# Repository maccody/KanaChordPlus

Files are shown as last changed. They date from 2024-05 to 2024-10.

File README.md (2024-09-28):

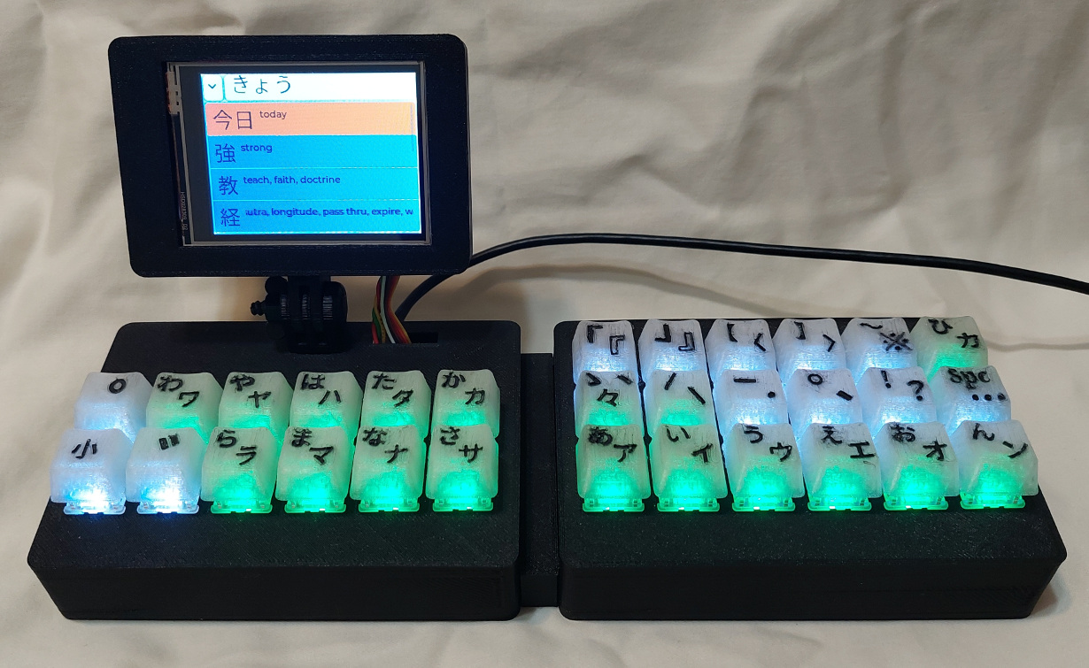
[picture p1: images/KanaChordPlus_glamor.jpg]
KanaChord_glamor

# KanaChord Plus Keyboard 【カナコード・プラス・キーボード】
## Overview 【概要】
KanaChord Plus is an auxiliary keyboard that works in parallel with a standard English keyboard and generates Unicode keyboard macros to render Japanese Kana and Kanji characters.  This allows the user to immediately start typing in Japanese on any supported computer, rather that installing special software and switching language input modes on a single keyboard.  KanaChord Plus can assist the Japanese learner by providing another means to improve their language skills by typing in Japanese, in addition to practicing their reading and speaking skills.  Note that during the composing of this README, KanaChord Plus Keyboard was used to type the Kana and Kanji characters displayed.  KanaChord Plus is a follow-on project of KanaChord Keyboard, which supports typing of just Hiragana and Katakana Unicode characters.

### Writing in Japanese 【日本語で書く】
The Japanese writing system consists of three components: Hiragana, Katakana, and Kanji. Hiragana consists of 48 syllabic characters that are used for some words of Japanese origin and grammatical sentence fragments, e.g., あなた, これ, の (‘you’, ‘this’, possessive particle).  Katakana also consists of 48 syllabic characters that are used for foreign loan words and names, e.g., テーブル, クッキー, マック (‘table’, ‘cookie’, ‘Mac’).  The table below shows the syllabary of Hiragana and Katakana, known collectively as the Kana.
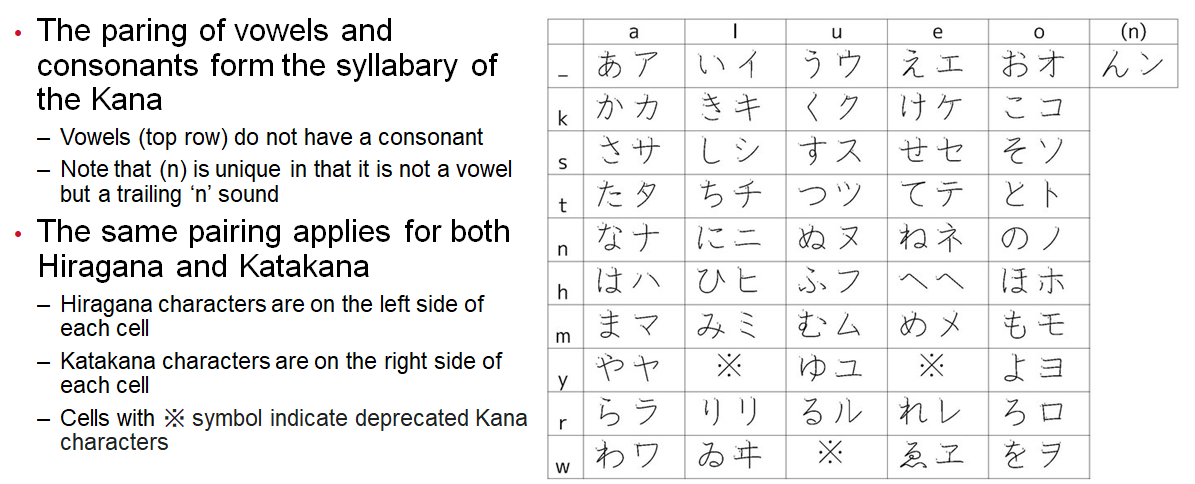
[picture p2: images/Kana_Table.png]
Kana Table


### What about Kanji? 【漢字はどうですか？】
Kanji consists of Chinese logography and conveys main ideas and names in sentences.  A Japanese word containing Kanji can consist one or more Kanji characters, e.g., 私, 東京, 日曜日 (I, Tokyo, Sunday), and Hiragana e.g. 買い物、ご飯、寒い (shopping, meal, cold).  There are currently about fify-thousand Kanji characters and new ones are added on occassion.  In Japan, it is expected that a graduating high-school student, starting from elementary school, learn the Jōyō Kanji【常用漢字】, which contains 2136 Kanji characters that are reqularly used or are found in government documents.  A college graduate, especially with an advanced degree, would be expected to learn a thousand or more additional Kanji usually associated with their major.

### Inspiration for a Keyboard 【キーボードの動機】
Over the last century, there have been a number of mechanical and electro-mechanical keyboards have been developed to type Kana and Kanji characters.  A quick web search for 'japanese keyboard' will provide a number of interesting links to follow.  These keyboards all shared common problems.  They were very expensive and slow at typing compared to contemporary English typewriters.  Only a relatively small subset of Kanji (a few thousand) were suported with these typewriers.

The availability of inexpensive computers in recent decades have obsoleted these typewriters, They have replaced purely hardware solutions with ubiquitious keyboards augmented with software running on the computer.  [There are two methods for typing in Japanese](https://www.coscom.co.jp/learnjapanese801/howjpdo.html).  The first is Romaji Input (ローマ字入力, romaji nyūryoku), which uses combinations of Roman characters to represent Japanese syllables. The second is Kana Input (仮名入力, kana nyūryoku), which uses Japanese Kana characters directly.  The more commonly used method is Romaji Input due to the fewer number of characters on the keyboard to remember.  *Comment: I find it a little sad that a foreign character set has taken precedence over the Japanese native characer set for typing in Japanese!*  Software on the computer implements an Input Method Editor (IME) that takes Romaji Input or Kana Input and predicts one or more Japanese words that may contain Kanji. Junferno's video [The Challenge of Making a Keyboard for Every Language](https://www.youtube.com/watch?v=MBQvN03i4-4) provides a nice overview of the difficulties of creating a keyboard that supports non-English characters and the succession of typewriters by computers with keyboards and IMEs. 

The layout of the Kana table inspires a chording keyboard input method. Chording is where multiple keys are pressed simultaneously on the keyboard to obtain a desired character output.  A [Stenotype](https://en.wikipedia.org/wiki/Stenotype) keyboard is an example of a chording keyboard that is used by court recorders and stenographers.  The illustration below provides further explanation and demonstration of how chording is used on the KanaChordPlus Keyboard.
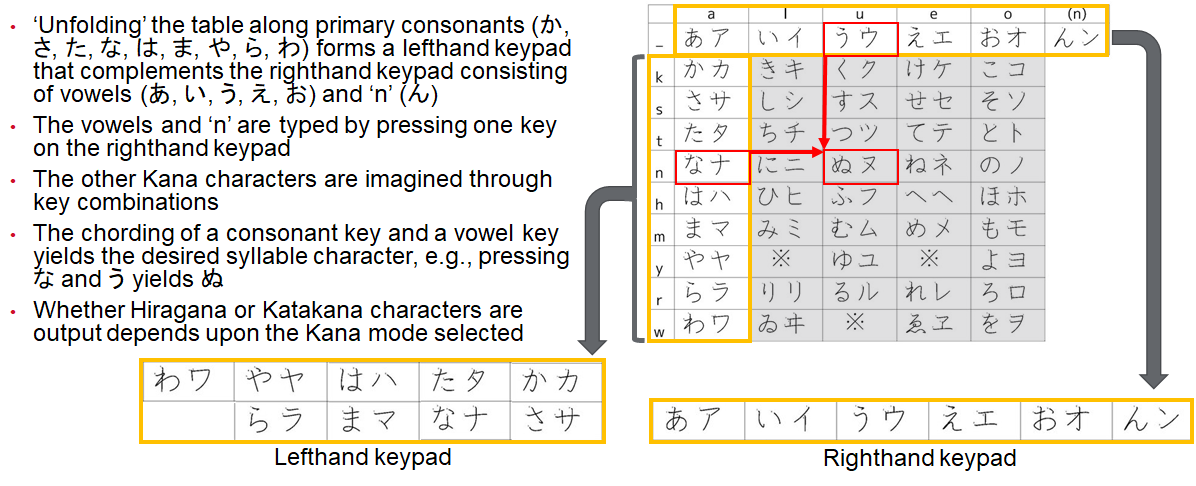
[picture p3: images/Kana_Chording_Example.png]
Kana Chording Example


A chording keyboard concept is sufficient for generating all of the Kana.  It is impractical for Kanji, though, as even a chording keyboard would quickly become impractical when attempting to support more than a few dozen Kanji.  Instead, KanaChord Plus incorporates an 'incremental' IME.  As the Hiragana or Katakana are typed, they are presented on a touch screen along with a list of representative Kanji characters and/or Japanese words containing Kanji.  The list is updated with each new Kana character typed, incrementally.  This is not a word-predictive IME, as the Kanji and Japanese words presented are only those corresponding to the Kana currently typed.  The user can either send the Kana characters typed to the computer or select one of the Kanji characters or Japanese words to replace the Kana characters and send that to the computer instead.

## Features 【特徴】
### Dynamic Key Coloring 【動的なキーの色付け】
KanaChordPlus includes dynamic key coloring that provides indication of character type, Kana mode, and error feedback.  The three Shift keys on the left keypad are normally white:
- Voicing mark, a.k.a. dakuten or ten-ten (ﾞ),
- Plosive mark, a.k.a. handakuten or maru (ﾟ),
- Small characters, a.k.a. chiisai (小), also used to ‘shift’ to alternate punctuation and special characters.

Punctuation keys on the top two rows of the right keypad are also normally white:
- Vertical iteration mark (〳,〴,〵), continuation mark (ー), and separation (・) characters ,
- Sentence pausing (、) and ending characters (。, ! , ?),
- Wide space (labeled **Spc**) and ellipsis (…) characters,
- Commonly-used quotation (「, 」,『, 』), bracket (【, 】,〈, 〉), and special (〜,※) characters.

The Kana and horizontal iteration mark keys (ゝ,ゞ,ヽ,ヾ、々) are green for Hiragana mode or blue for Katakana mode.  The mode is selected by the mode key (ひカ) at upper right-hand corner of the right keypad.
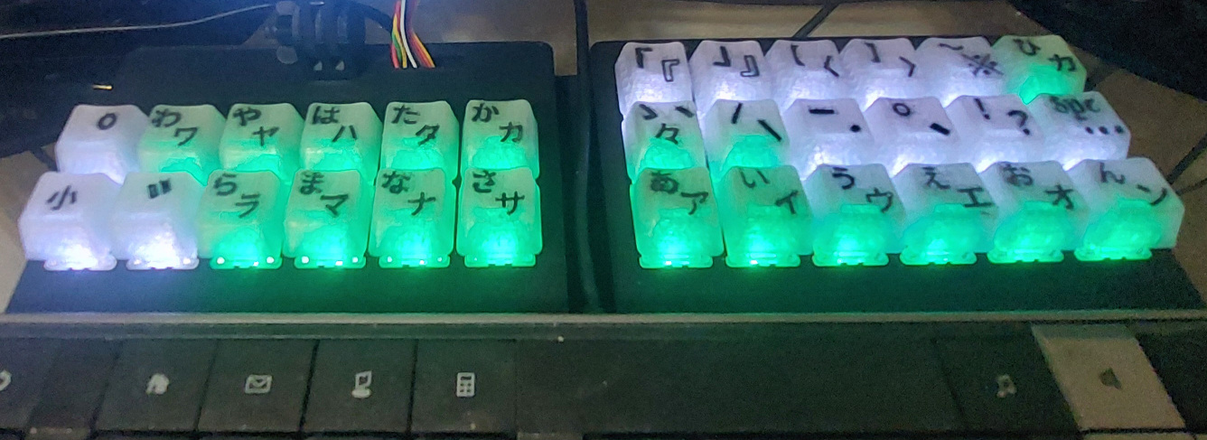
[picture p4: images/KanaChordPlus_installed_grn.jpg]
KanaChordPlus_installed_grn

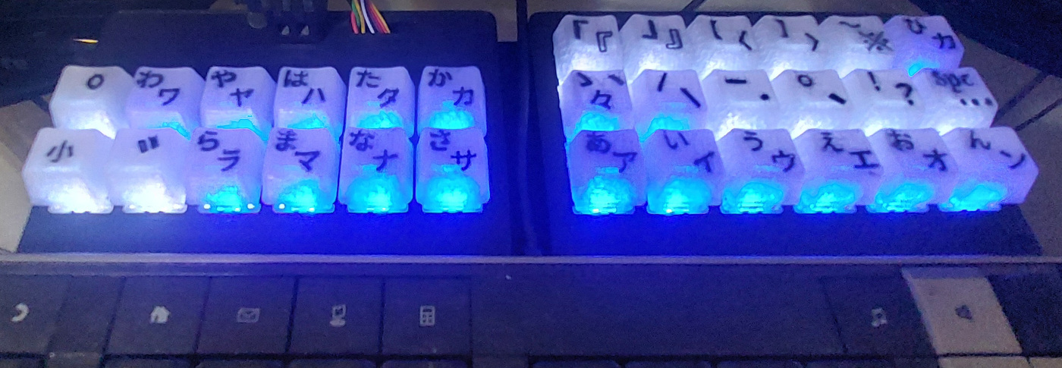
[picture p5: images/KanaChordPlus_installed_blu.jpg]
KanaChordPlus_installed_blu


### Error Feeback 【エラーフィードバック】
Feedback is provided to the user for incorrect key combinations by changing those keys red.  Releasing the keys will cause the keys to revert to their original colors.  Some examples are provded below:

Keyboard error lighting with press of ! and お key combination.
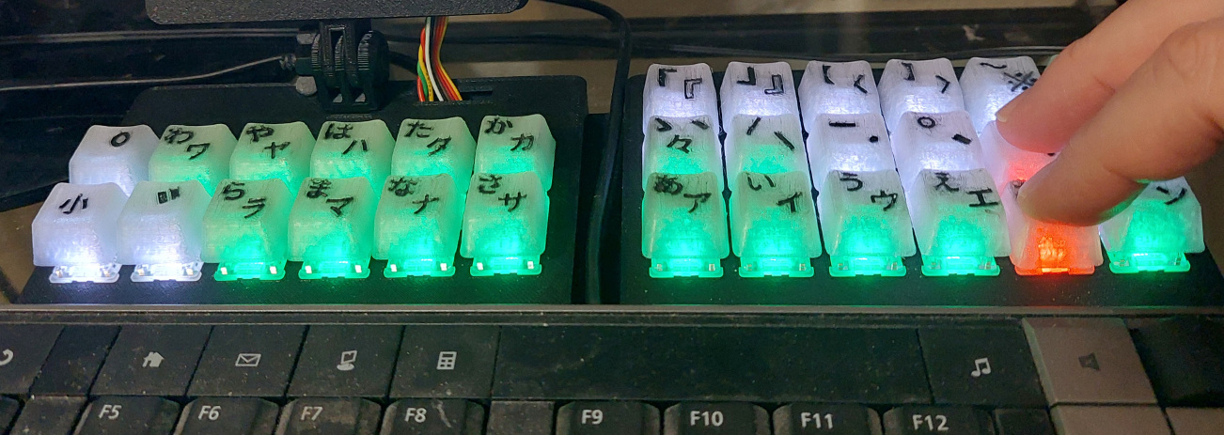
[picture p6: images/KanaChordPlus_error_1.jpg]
KanaChordPlus_error_1


Keyboard error lighting with press of ﾞ, な, and あ key combination.
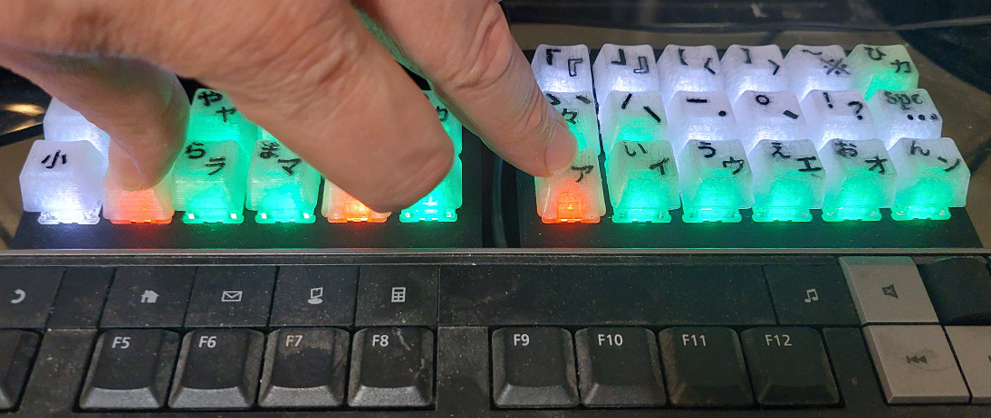
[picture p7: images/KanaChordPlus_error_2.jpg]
KanaChordPlus_error_2


### 'Incremental' Input Method Editor 【「インクリメンタル」インプットメソッドエディター】
As mentioned previously, Kanji characters and Japanese words containing Kanji are typed via an 'incremental' Input Method Editor (IME).  Over 6,100 of the most common Kanji charaters and over 6,200 of the most common Japanese words containing Kanji are available in KanaChord Plus.  

As Kana characters are typed, they are presented at the top of the KanaChord Plus display in an single-line Editor Window.  The Editor Window can hold up to nine characters, either Kana or Kanji.  If only Kana characters have been typed, they can be sent to the computer by pressing any punctuation or special character mentioned previously.  The Kana characters will be displayed on the computer followed by the punctuation or special character pressed, with the exception of the wide space character.  Japanese writing does not normally have spaces between words, so it would be unusual to include the wide space character in the output.  To purposely display a wide space character, make sure the Editor Window is empty of characters first before pressing the wide space (**Spc**) key.

Below the Editor Window, a Kanji List Window is presented, its content consisting of Japanese words with Kanji and Kanji characters.  The content of the Kanji List is updated as new Kana character are entered, i.e., incrementally.  The list is displayed with Japanese words presented first, followed by Kanji characters ordered according to the most commonly used first.  The color of each entry indicates whether it is a word or particular Kanji reading:  
- Orange - Japanese word containing Kanji
- Green - The kunyomi or Japanese reading for the Kanji
- Blue - The onyomi or Chinese reading for the Kanji
- Brown -The nanori or name reading for the Kanji

Each entry in the Kanji List has two parts.  On the left side, the kanji character or word (one or more Kanji, sometimes with Kana) is presented.  On the right side, a definition in English is presented.  Definitions are provided to aid the user in making the appropriate selection.  Note that each entry on the list is pronounced according to the Kana present in the Editor Window, i.e., they are homophones, sounding the same.  

The procedure for selecting a Japanese word or Kanji character is illustrated in the animated GIFs below.  Note that the left portion of a Kanji List entry must be pressed to select the Kanji or Japanese word.  Pressing the definition portion of an entry will not cause a selection.  
 Typing 今 (now)           | Close-up (Refresh webpage if out of sync)
:-------------------------:|:-------------------------:
KanaChordPlus_demo|KanaChordPlus_demo_inset

 Typing こにちは！コーディです。 (Hello! I am Cody)| Close-up (Refresh webpage if out of sync)
:-------------------------:|:-------------------------:
KanaChordPlus_demo|KanaChordPlus_demo_inset

 Typing 今何時ですか？(What time is it now?) | Close-up (Refresh webpage if out of sync)
:-------------------------:|:-------------------------:
KanaChordPlus_demo|KanaChordPlus_demo_inset

Once a Kanji or Japanese word has been selected, it can be sent to the computer by typing any Kana, punctuation, or special character.  If a Kana character is a typed, it is displayed in the Editor window, the previous content being sent to the computer.  This allows the user to build up the next set of Kana characters to form a new word or Kanji.  If a punctuation or special character is typed, it gets sent along with the current contents of the Editor Window.  The behavior of the wide space character is the same as mentioned previously, 

The length of the Kana List generated can exceed that of the vertical extent of the display.  The list can be scrolled by dragging on it with a finger, up or down, along the right portion of the list.  Up to ten entries of the current list are displayed at any time.  If more than ten entries are in the list, special navigation entries are provided at the beginning and end of the list, as necessary. When an entry with a down arrow is shown at the bottom of the list, pressing it will cause display of the next set of less common Kanji (move further down the list).  When an entry with an up arrow is shown at the top of the list, pressing it will cause the display of the next set of more common Kanji (move back up the list).  

Some Kanji characters with kunyomi readings have associated okurigana, or following Kana characters.  If the Kanji character selected from the Kanji List has a kunyomi reading (green) and has okurigana, an Okurigana Window appears.  The button in the upper left hand corner of the window contains the Kanji character by itself.  Pressing this button will dismiss the window and cause just that Kanji character to replace the Kana in the Editor Window.  A Cancel buttion is in the upper right hand corner of the window.  Pressing the Cancel button dismisses the window without making any change to the Editor Window.  Below these buttons is a list of Kanji with the associated okurigana on the left and one of three informative remarks in English:  
- Simple reading - The Kanji and Kana characters form a standalone word
- Prefix reading - The Kanji and Kana characters come before other Kanji to form a word
- Suffix reading - The Kanji and Kana characters come after other Kanji to form a word

Scrolling and selection of Kanji within the Okurigana Window follows the same methods as explained for the Kanji List.  No navigation entries are provided because the list of Okurigana is always short.

 Typing 見える (appear) | Close-up (Refresh webpage if out of sync)
:-------------------------:|:-------------------------:
KanaChordPlus_demo|KanaChordPlus_demo_inset

### Support Menu 【サポートメニュー】
Pressing on the inverted caret at the upper left-hand corner of the display will a show a dropdown menu listing several support functions.  The first two entries support making changes to the Editor Window.  The last two entries support configuration of KanaChord Plus.
- **Delete last character** - Deletes the last character present in the editor window.  The word and Kanji list is regenerated according to the characters now present in the editor window.  Note that the content of the Kanji List may not be valid if there are Kanji characters in the editor window.
- **Clear input and Kanji list** - Deletes the content of the editor window and clears the Kanji List.
- **Select Macro output mode...** - Opens a window for Unicode key sequence selection.  Press the button labeled with a **checkmark** to save the selected mode to flash memory.  Press the button labeled with an **x** to close the window, abandoning any changes.  KanaChord Plus can output different Unicode key sequences to support different operating systems and applications.  There are currently three settings available:
  - Four-character hexidecimal Unicode value, followed by Alt-X: Supports Microsoft Word and Wordpad, and LibreOffice Writer.
  - Ctrl-Shift-u, followed by four-character hexidecimal Unicode value: Supports Linux applications like LibreOffice Writer and Firefox.
  - Option key, followed by four-character hexidecimal Unicode value: Supports MacOS applications (not yet tested).
- **Calibrate Screen...** - Opens a window to prompt the user to initiate touch screen calibration.  To function properly, the touch screen of the KanaChord Plus display needs to be calibrated.  When the window opens, the user has the option of starting a calibration or closing the window without performing a calibration.  Follow the instructions displayed in the window to perform the calibration.  Once the calibration steps are completed, the calibration values are automatically saved to flash memory.  The user can then close the window or repeat calibration, if desired.  Note that the first time KanaChord Plus is used after programming the Raspberry Pi Pico, the calibration screen will be automatically displayed to require the user to calibrate the touch screen.

## Implementation Overview 【実装の概要】
The primary electical componets of the KanaChord Keyboard are a Raspberry Pi Pico (RP2040) microcontroller, an Adfruit NeoKey 5x6 Ortho Snap-Apart keyboard PCB, a 2.8 inch, 320x240 TFT touch screen display using an IFI9341 controller, and thirty Cherry MX mechanical key switches.  The keycaps and keyboard enclosure are 3D printed designs created with TinkerCAD.  Blank keycaps and an OpenSCAD tight-fit box generator were found on Thingiverse.  No special hardware, such as screws are needed to mount the electrical components and assemble the enclosure.  Details on the electronics, enclosure, and their assembly can be found in the [README.md](./hardware/README.md) in the hardware subdirectory.

KanachordPlus' software was developed with the Arduino IDE (version 1.8.19), Earle Philhower's RP2040 board support package, and LVGL (Light Versatile Graphics Library) version 8.4.  The USB Keyboard library, Adafruit Neopixel library, and Mark Stanley's Key and Keypad libraries provided critical software functions.  Details on the software can be found in the [README.md](./software/README.md) in the software subdirectory.

## Hardware and Software Licenses 【ハードウェアとソフイウェアのライセンス】
Cc_by-nc-nd_icon svg
KanaChordPlus' circuit design and the STL files for the keycaps, component mounting parts, and enclosure parts are placed under Creative Commons Attribution-NonCommercial-NoDerivatives license.

GNU_GPL_V3
KanaChord Plus' source code that I wrote (KanaChordChordPlus.ino, dictionary.h, display.cpp, display.h, kana.h, kanji_md.h, kanji_ms.h, kbd_mgt.cpp, kbd_mgt.h, kdict.cpp, kdict.h, kunyomi.h, loop1.h, nanori.h, onyomi.h, settings.cpp, and settings.h) are placed under GNU General Public License, Version 3.0.

The slightly-modified versions of Mark Stanley's Key and Keypad libraries (Key2040.cpp, Key2040.h, Keypad2040.cpp, and Keypad2040.h) fall under the license of the original sources.

## Feedback is Welcome! 【フィードバックは大歓迎です！】
My goal is to provide an axuilary keyboard that is useful to those who want to start writing in Japanese on a computer, while learning Japanese.  I hope to have provided operational features, keycaps, and Asian special characters that would most likely be used.  If you have recommendations for additional features, alternate keycaps, or Asian special characters, please let me know.  I will accomodate as many recommendations as feasible.

## The Future of KanaChord Plus Keyboard 【カナコード・プラス・キーボードの今後】
The recent (August 2024) announcement of the Raspberry Pi Pico 2 provides a direct upgrade path for several features in KanaChord Plus:
- Since the Pico 2 is a drop-in replacement for the Pico 1, there will be no changes in the electronics hardware, unless new capabilities are added that require it.
- The higher performance of the RP2340 microcontroller will make the KanaChord Plus software run faster and be more responsive.
- The increase in size of the flash rom from 2 MB to 4 MB will enable a significant increase in the number of Kanji and/or Japanese words supported.

There will be a delay in updating KanaChord Plus to use the Pico 2, as it will take some time for component availabiltiy and updates to software libraries.  This Github site will be updated when support for the Pico 2 is realized.

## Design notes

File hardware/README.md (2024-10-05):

# KanaChord Plus Hardware

## Electronics Components
KanaChord Plus keyboard uses following electronics parts:
- 1 x Raspberry Pi Pico microcontroller
- 1 x [Adfruit](https://www.adafruit.com) [NeoKey 5x6 Ortho Snap-Apart Mechanical Key Switches w/ NeoPixel - For MX Compatible Switches](https://www.adafruit.com/product/5157)
- 30 x Cherry MX RGB frame-mount mechanical key switches, e.g., [Cherry MX Brown Switches](https://www.cherrymx.de/en/cherry-mx/mx-original/mx-brown.html) (does not count spares)
- 1 x 2.8" 240x320 pixel TFT Display using a ILI9341 controller and a resistive touch screen using a XPT2046 controller [front](./images/display_front.jpg), [back](./images/display_back.jpg)
- 1 x BC547 (or equivalent) NPN transistor
- 1 x 2.2 Kohm 1/8 Watt resistor
- 1 x 6.8 Kohm 1/8 Watt resistor
- 31 x 0.1" Spacing Row Right Angle Headers (does not count spairs), e.g., [Schmartboard brand](https://schmartboard.com/qty-10-0-1-spacing-40-single-row-right-angle-headers-920-0076-01/)
- 3 x Seven-position ITT connector shell - (e.g., Adafruit [Large Single Row Housing Pack](https://www.adafruit.com/product/3146))
- 3 x Five-position ITT connector shell - (e.g., Adafruit [Small Single Row Wire Housing Pack](https://www.adafruit.com/product/3145))
- 1 x Four-position ITT connector shell - (e.g., Adafruit [Small Single Row Wire Housing Pack](https://www.adafruit.com/product/3145))
- 4 x Three-position ITT connector shell - (e.g., Adafruit [Small Single Row Wire Housing Pack](https://www.adafruit.com/product/3145))
- 41 x Female crimp contact pins (does not count spares)
- 5 x Male crimp contact pins (does not count spares)
- 1 x 12 inches of Forty-conductor ribbon cable
- 1 x USB A to USB Micro B cable
- Random short lengths of stranded hook-up wire
- Heat-shrink tubing for enclosing the unidirectional level shifter

## Keyboard Schematics
Below is a pictorial schematic of the keypad portion of the KanaChord Plus keyboard.

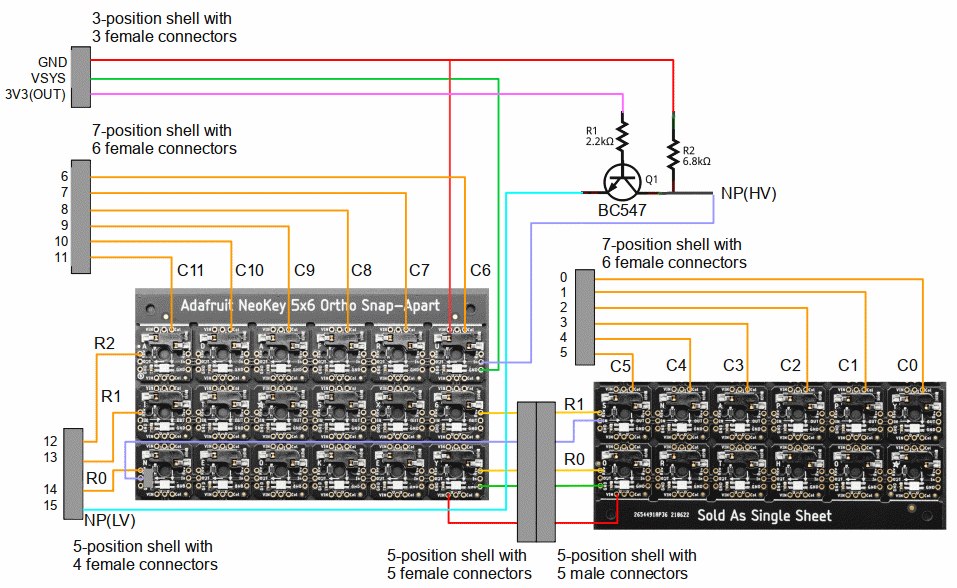
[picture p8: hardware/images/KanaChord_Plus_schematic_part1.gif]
Keypad_Schematic


While the Neopixels of the Ortho Snap-Apart board can opperate at 3.3 Volts, the 3.3-Volt regulator on the Pico cannot supply enough current.  Therefore, the Neopixels are powered by the Pico's 5-Volt VSYS output.  Consequently, a unidirectional level shifter is used to convert the low-voltage Neopixel signal, NP(LV), to a high-voltage Neopixel signal, NP(HV).  The BC547 and resistors are used to implement the unidirectional level shifter circuit.

Below is a pictorial schematic of the Raspberry Pi Pico and display portion of the KanaChord Plus keyboard.

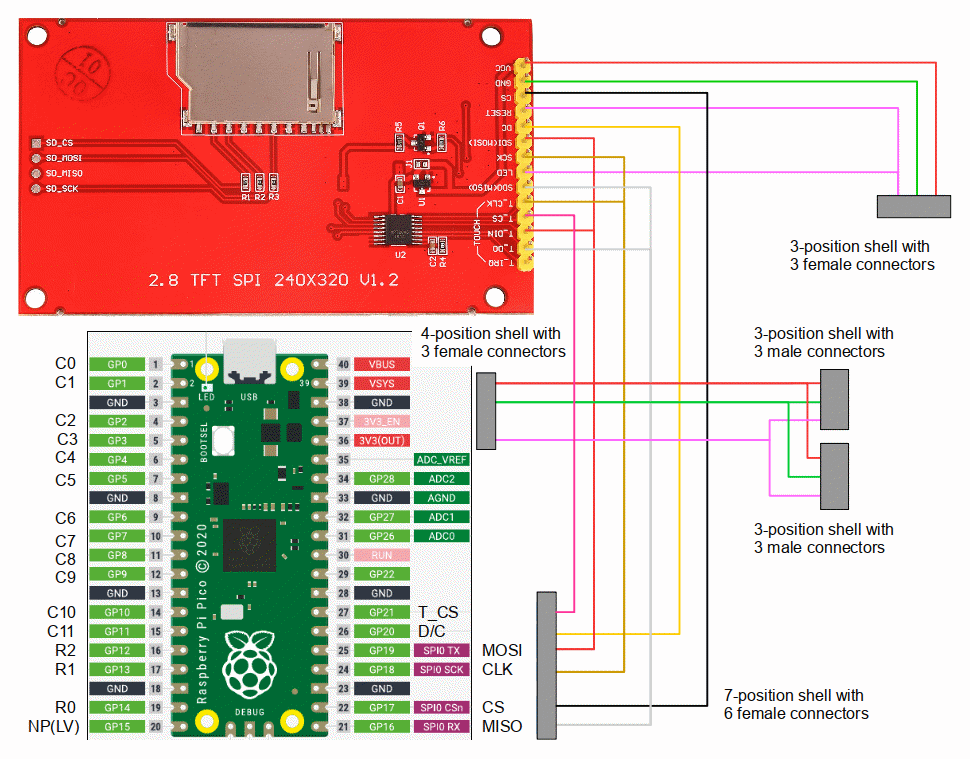
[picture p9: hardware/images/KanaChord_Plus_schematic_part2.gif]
Pico_Schematic


Right-angle header pins are soldered in 'gull-wing' fashion to pins 1 through 20, 21 through 27, and 36 through 39 of the Pico.  The connectors for the various cables are plugged into the headers during the electrical assembly.

## Electrical Assembly
### Keypad Preparation
Before soldering the keypad wiring harnesses, the snap-apart keyboard must be broken into two pieces to form two PCBs (Printed Circuit Boards) for the left and right keypad assemblies.  As shown in the pictoral schematic above and the pictures below, cut apart the keyboard so that the bottom two rows form the left keypad and the top three rows form the right keypad.  
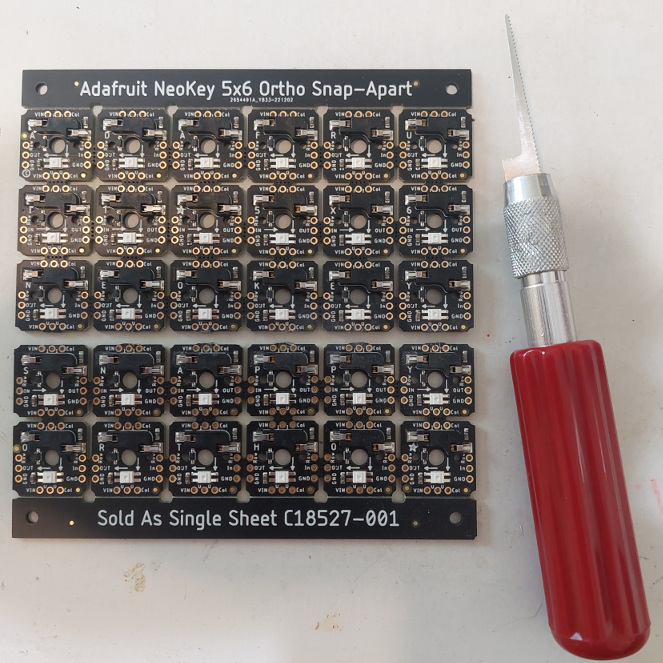
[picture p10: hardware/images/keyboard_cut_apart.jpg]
NeoKey_cut_apart


Rather than actually bending the PCB to snap it, it is recommended to use a thin saw to cut the bridges between the rows.  DO NOT cut off the blank sections on the top and bottom of the PCB, as the mounting holes will be used to help position the keypads in the keyboard enclosure.

### Left Keypad Wiring
The wiring of the left keypad assembly is shown in the picture below.  Take note the direction and length of the wires that extend from the left-hand keypad PCB.

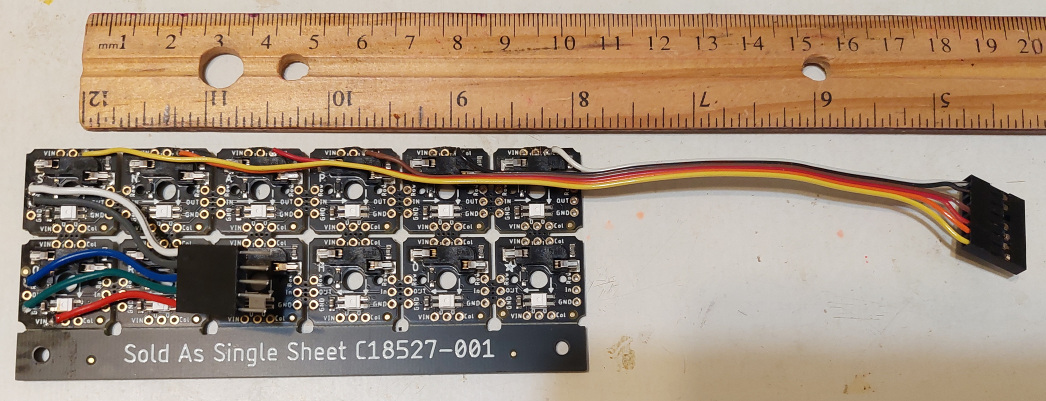
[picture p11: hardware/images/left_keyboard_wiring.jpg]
left_keyboard_wiring


First, cut a six-conductor section of ribbon cable with a length of approximatly 19 cm (7.5 inches).  This will be the column cable for the left keypad.  Separate out the individual conductors for about 3 cm (one inch), attach six (6) female crimp terminals, and insert the terminals into a seven (7) terminal connector shell.  Note that there will be an unused place between the terminal pins for Columns 1 and 2, which is Ground Pin 3 on the Pico. Then, as shown in the picture, start at the left end of of the keypad PCB and solder a conductor to a column solder pad. Work towards the right end of the keypad, shortening the length of the conductor to match to the column solder pad location, while keeping the ribbon cable parallel to the PCB. Note that during installation, this cable will fold over to attach to Pins 1 through 7 on the Pico.

Next, create the male keypad interconnect harness using five (5) male crimp terminals. This is a short cable, with a length of approximately 3 cm (1.25 inches), it is recommended to use separate wires, rather than a ribbon cable. A five (5) terminal connector shell is used for this harness. Use the pictorial schematic above for wiring directions. This completes the wiring of the left keypad assembly.

### Level Shifter Assembly
Prior to wiring the right keypad assembly, assemble the unidirectional level shifter circuit.  This can be assembled free-form, as it only has three components.  Doing this keeps the resulting assembly small and relatively flat.  

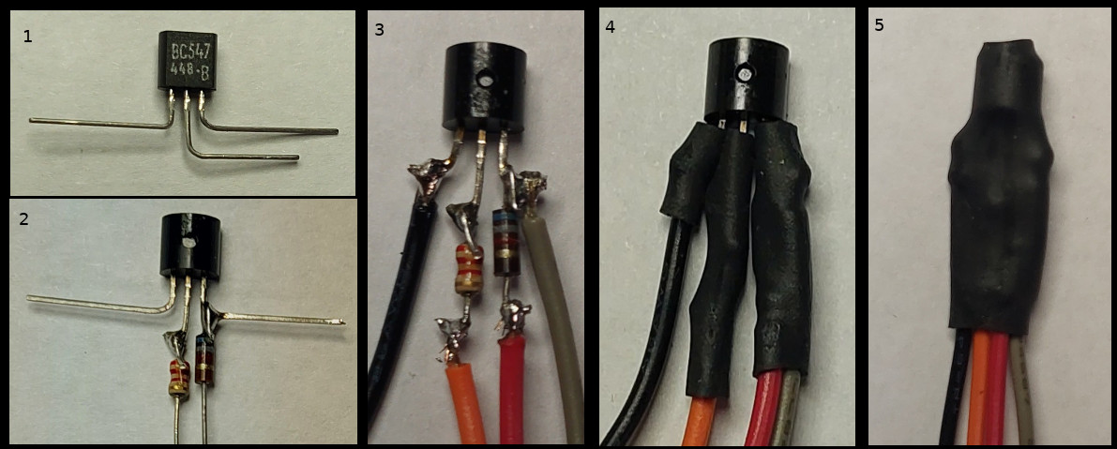
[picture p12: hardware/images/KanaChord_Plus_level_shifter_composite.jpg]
Level Shifter Composite Image


1. With the flat side of the BC547 transistor facing up, bend the leads as shown.
2. Flip the transistor's flat face down.  Solder the 2.2K resistor to the center pin of the transistor.  Solder the 6.8K resistor to the right pin of the transistor.  Cut off the excess leads on these pins.
3. Solder insulated wires to the left pin of the transistor, the opposite end of each resistor, and at the point where the 6.8K resistor is soldered to the right pin of the transistor.  Make sure that each wire has sufficient length for wiring to the keypad.  **It is highly recommended to use wires that have insulation of different colors to keep track of their functions!**
4. Apply heat-shrink insulation to cover up to the bottom of the transistor.  This will prevent any of the component leads from accidentally shorting.  Note that the two leads on the right side of the circut are covered with one length of shrink-wrap insulation.
5. Cover the entire assembly with a length of heat-shrink insulation.  Doing this will 'encapsulate' the assembly and keep the pins of the transistor from bending and eventually breaking.

### Right Keypad Wiring
The wiring of the right keypad assembly is shown in the picture below. Again, take note of the direction and length of the wires that extend from the right-hand keypad PCB.  

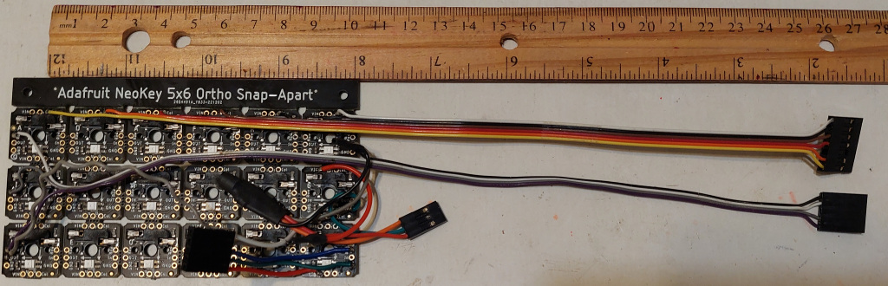
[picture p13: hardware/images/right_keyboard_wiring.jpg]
right_keyboard_wiring


First, cut a six-conductor section of ribbon cable with a length of approximatly 26 cm (10.25 inches).  This will be the column cable for the right keypad.  Separate out the individual conductors for about 3cm (1.25 inches), attach six (6) female crimp terminals, and insert the terminals into a seven (7) terminal connector shell.  Note that there will be an unused place between the terminal pins for Columns 9 and 10, which is Ground Pin 13 on the Pico. Then, as shown in the picture, start at the left end of of the keypad PCB and solder a conductor to a column solder pad. Work towards the right end of the keypad, shortening the length of the conductor to match to the column solder pad location, while keeping the ribbon cable parallel to the PCB. Note that during installation, this cable will fold over to attach to Pins 9 through 15 on the Pico.

Next, create the female keypad interconnect harness using five (5) female crimp terminals. This is a short cable, with a length of approximately 3 cm (1.25 inches), it is recommended to use separate wires, rather than a ribbon cable. A five (5) terminal connector shell is used for this harness. Use the pictorial schematic above for wiring directions.

Now, cut a four-conductor section of ribbon cable with a length of approximatly 28 cm (11 inches).  This will be the row cable for the right keypad.  Separate out the individual conductors for about 3 cm (1.25 inches), attach four (4) female crimp terminals, and insert the terminals into a five (5) terminal connector shell.  Note that there will be an unused place between the terminal pins for Rows 0 and 1, which is Ground Pin 18 on the Pico. Note that three of the ribbon cable conductors attach to the Row solder pads on the right keyboard PCB, while one conductor attaches to the signal input of the level shifter circuit. Note that during installation, this cable will fold over to attach to Pins 16 through 20 on the Pico.

The level shifter is wired into the power harness, which is approximately 10 cm (3.5 inches) long.  The power harness has three (3) female crimp connectors that are inserted into a three (3) terminal connector shell.  Consult the pictorial schematic above for the wiring of the level shifter circiut, with the output of the level shifter connected to the Neopixel input and the power harness 5V and Ground to the right keyboard PCB. During installation, the power harness connector will attach to the Power Wye described below. This completes the wiring of the right keypad assembly.

### Display Wiring
The wiring for the display is shown in the picture below.

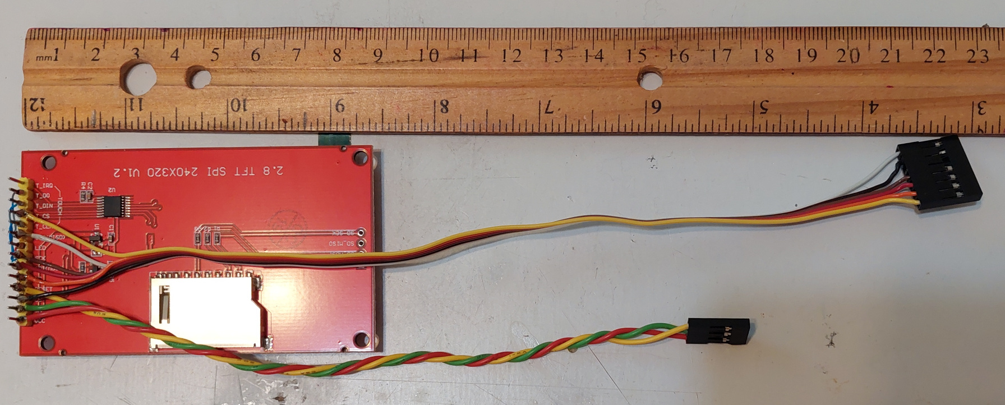
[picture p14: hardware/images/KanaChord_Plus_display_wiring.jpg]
display_wiring


Prior to attaching the wiring harness to the display pins, it is necessary to connect the respective SDI CLK, MOSI, and MISO pins of the display and touch screen interfaces, The board RESET and LED pins are also connected together.  This can be accomplished with any small gauge wire.  Kynar-insulated wire-wrap wire works well for this application.

Cut a six-conductor section of ribbon cable with a length of approximatly 22 cm (8.75 inches).  This will be the SPI inteface cable for the display.  Separate out the individual conductors for about 3 cm (1.25 inches), attach six (6) female crimp terminals, and insert the terminals into a seven (7) terminal connector shell.  Note that there will be an unused place between the SPI clock and chip select, which is Ground Pin 23 on the Pico.

At the other end of the wiring harness, separate out the individual conductors for about 5 cm (2 inches).  Attache the six wires to the SPI's SCK, MISO, MOSI, DC, and CS lines for the display controller and touch screen controller.  Consult the pictorial schematic of the Pico and display wiring for details.

The power harness for the display consists of three wires twisted together.  The length of each wire should be about 16 cm (6.5 inches).  Attach three (3) female crimp terminals, and insert the terminals into a three (3) terminal connector shell.  Connect the other end of each wire to the 5V power, ground, and RESET/LED pins.  The RESET/LED pins are supplied 3.3V to keep the display controller running and the display fully lit.  During installation, the power harness connector will attach to the Power Wye described below. 

### Power Wye
The wiring of the power wye is shown in the picture below.  

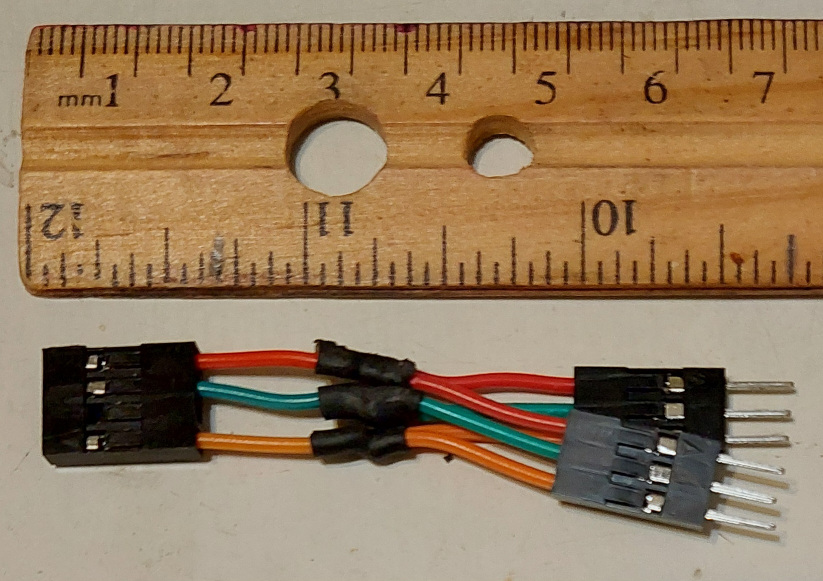
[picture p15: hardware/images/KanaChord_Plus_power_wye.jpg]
power_wye


The overall length of the wires should be approximately 6 cm (2.25 inches).  Each wire is spliced half way to form two wires.  Each is covered with heat-shrink tubing.  Nine (9) crimp terminals (three female, six male) are attached to the ends of the wires.  As shown in the picture, insert the terminals at the 'top' of the wye into two, three (3) terminal connector shells.  Make sure to keep the wiring order consistent between the two connectors.  The terminals at the 'bottom' of the wye are inserted into a four (4) terminal connector shell.  Note that there will be an unused place between the terminal pins for 2 and 4, which is 3V3_EN Pin 37 on the Pico.

## 3D-Printed Keycaps
The keycaps for the KanaChord Plus Keyboard were created in TinkerCAD, as shown in the illustration below.  The STL files for the left-hand and right-hand keycap sets can be viewed with the Github STL viewer by clicking on the STL files listed above.

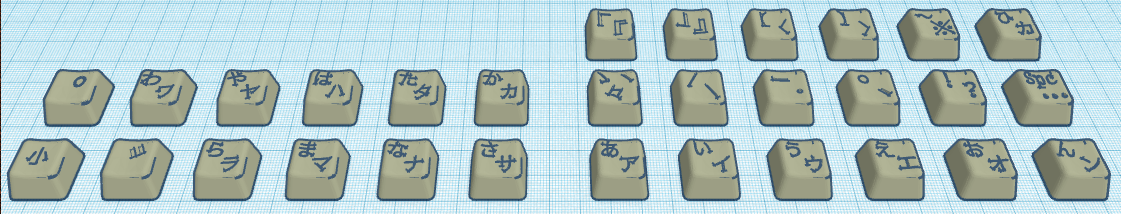
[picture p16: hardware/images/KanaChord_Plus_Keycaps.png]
KanaChord_Plus_Keycaps


The blank keycap from makerhack's (Chris Garrett) [Custom Cherry MX Keycaps](https://www.thingiverse.com/thing:4702109) was used as the source keycap.  The design is licensed under the [Creative Commons - Attribution license](https://creativecommons.org/licenses/by/4.0/). The Kana and special charaters are text objects converted to TinkerCAD 'holes' that are combined with blank keycaps to form insets. The keycaps were sliced with Cura using the Standard Quality (0.2mm) setting, with 20% infill using the gyroid infill pattern, and Tree supports were used. The keycaps were printed with untinted PLA to allow light from the Neopixels to shine through. After printing, the insets were filled with black acrylic paint, followed by a coat of flat, clear enamel paint.

## 3D-Printed Enclosure
The enclosure for the KanaChord Plus Keyboard was also created in TinkerCAD, as shown in the illustration below.  The STL files for the individual components of the enclosure can be viewed with the Github STL viewer by clicking on the STL files listed above.

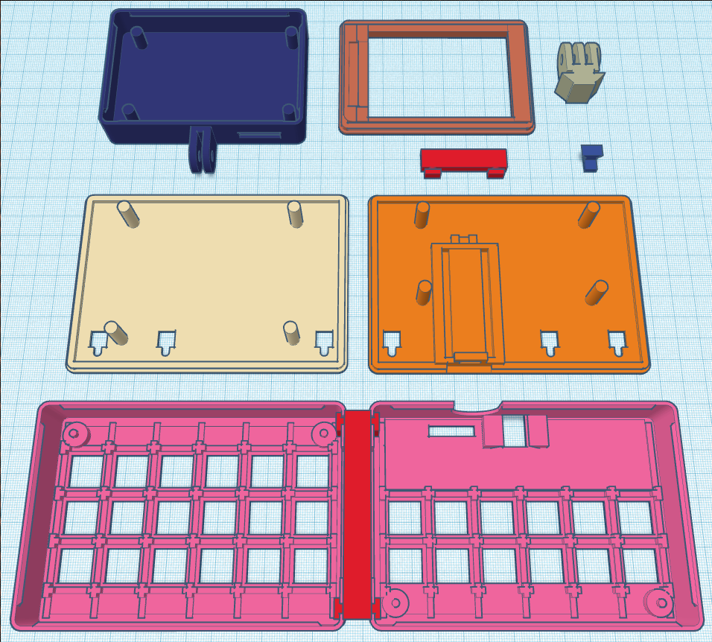
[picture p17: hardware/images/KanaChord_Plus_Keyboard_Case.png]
KanaChord_Plus_Keyboard_Case


The left and right keycase enclosures were created using 0707070user's OpenSCAD program [Customizable snap-fit electronics project box enclosure](https://www.thingiverse.com/thing:2866563). It is licensed under the [Creative Commons - Attribution license](https://creativecommons.org/licenses/by/4.0/). The enclosure components are flipped so that the lids now act as baseplates for the keyboard enclosure. The enclosures were edited to create the key switch holes of the integral keyplates, the Pico board mount, and pass-through holes for the keyboard feet, and the USB cable.  

The enclosure was designed in halves to fit on the build plate of a Crealty Ender 3 Pro 3D printer.  All components were sliced with Cura using the Low Quality (0.28mm) setting, with 20% infill using the standard in-fill pattern, and no supports were used.  The case components were prited in black PLA, although any color can be used, if desired.

The screw and wingnut were created using mike_mattala's OpenSCAD program [NUT JOB | Nut, Bolt, Washer and Threaded Rod Factory](https://www.thingiverse.com/thing:193647).  It is licensed under [Creative Commons - Attribution - Non-Commercial license](https://creativecommons.org/licenses/by-nc/4.0/).  Print the screw horizontally, so that the layers are parallel to the long axis of the screw.  This will provide strength to the screw along the axis of tension when the wing nut is tightened.  

## Mechanical Assembly
### Applying PCB Cushions
The keypad PCBs are connected to the key switches via sockets.  To prevent the PCBs from coming loose from the key switches, supports are provided to keep the PCBs in place. Two of these supports are shown in the photo below.

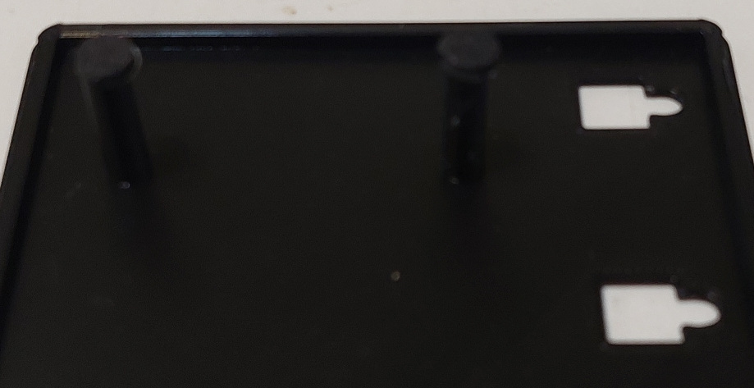
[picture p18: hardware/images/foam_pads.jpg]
foam_pads


The height of each support is such that there is about a 2mm (0.1 inch) gap from the top of the supports to the underside of the PCBs. To fill in the gap, a small disc of 2mm-thick craft foam is attached to top of each support with double-sided adhesive tape.  One way to make the discs is to apply a strip of double-sided tape to a piece of craft foam.  A single-hole hole punch is used to create the discs with the adhesive tape also cut to the same size as the disc.  Eight (8) discs will be needed for the supports.

### Mounting the Raspberry Pi Pico
The Pico is mounted to the left keyboard base by first inserting the end with the USB connector under the bridge of the processor mount at the edge of the keyboard base. Once this is done, push the opposite end of the Pico down into the depression of the processor mount. Finally, slide the retaining clip into the notches in front of the processor mount until the tab of the retaining clip is securely on top of the end of the Pico.

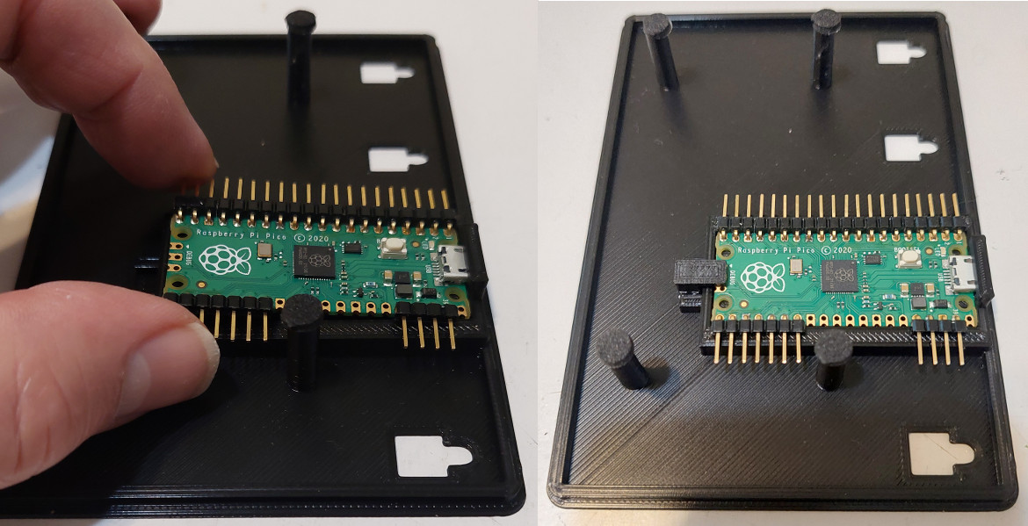
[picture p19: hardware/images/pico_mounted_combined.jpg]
pico_mounted_combined


### Break-in the Key Switch Sockets
Prior to mounting the key switches and keypad PCBs, it is highly recommended to 'break in' the key sockets on the keypads.  This is done by inserting a key switch into each key socket at least once.  The key sockets are a little 'stiff' with the first insertion of a switch.  Doing this will make it a bit easier to mount the key switches into the keypads and reduce the possibility of bending the tabs on the key switches.

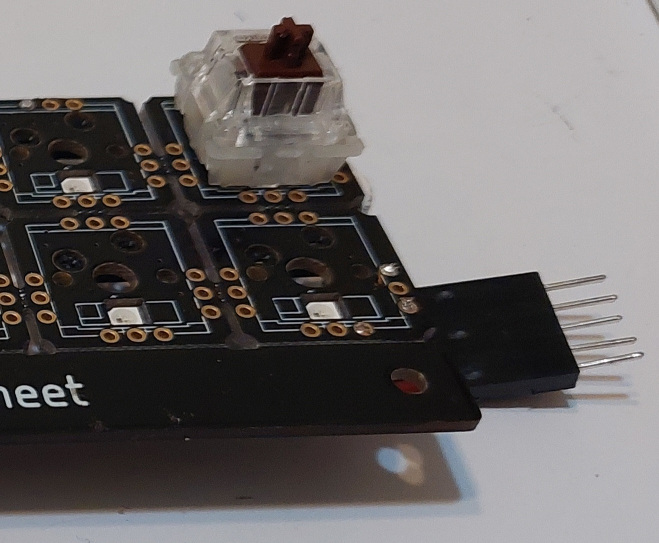
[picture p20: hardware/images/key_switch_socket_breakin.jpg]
key_switch_socket_breakin


### Preparing the Enclosures for the Key Switches
It may be necessary to slightly widen the keyplate holes on the enclosures prior to attaching the key switchs and keypads.  For any given hole, try to insert a key switch without any widening.  If a switch plugs in easily, then no widening is needed.  For those holes needing widening, use a flat-sided jewler's file to slightly widen all sides of the hole.  In practice, it should not take much filing to allow a switch to plug in easily.

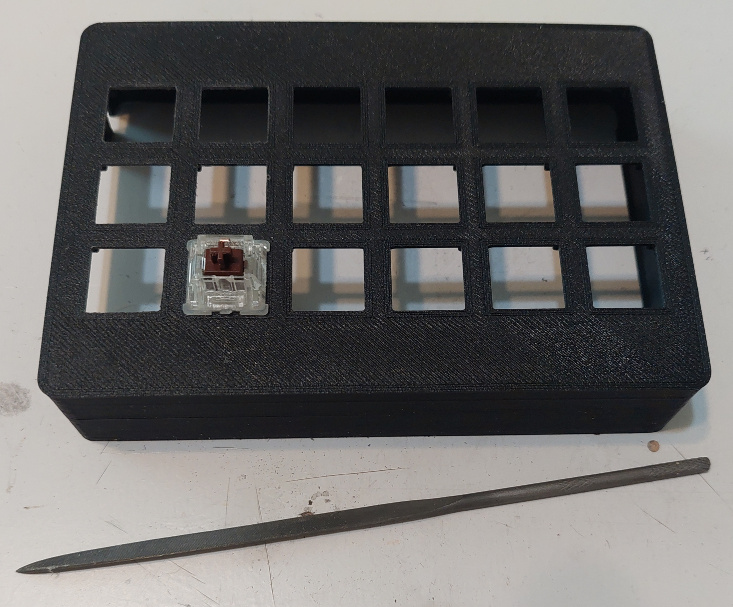
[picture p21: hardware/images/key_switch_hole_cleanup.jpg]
key_switch_hole_cleanup


### Mounting Key Switches and Keypad PCBs to the Enclosures

First, slide on the keyboard bracket on to the right keyboard enclosure.  Make sure that the bracket is inserted such that the side with the tabs flush to the bracket face is inserted first.  Next, place the three-row keypad PCB into right keyboard enclosure. The female keyboard interconnect connector, the column and row cables, and the power harness should slide through the opening in the keyboard bracket. Use the mounting pins, if present, to align the key sockets with the holes of the integral key plate.

Start at one end of the enclosure and insert a key switch through the hole of the keyplate into the socket of the PCB. Place a finger against the key socket, on the bottom side of the PCB, to support key switch insertion. Having a keycap on the switch will make it easier to press the switch in.  Once the switch is inserted, go to the opposite end and insert another key switch as before.  Doing this will stablize the PCB position for inserting the rest of the key switches.  Working from the ends towards the center of the enclosure, plug in more keys until all eighteen switched are plugged in.

Now insert the left keypad PCB into the left keyboard enclosure.  As with the right keypad, align the key sockets with the holes in the integral keyplate.  Insert the key switches, again working from both ends of the enclosure to the center.  Once all of the key switches are inserted, slide the left keyboard enclosure onto the other side of the keyboard bracket.  While doing this, fold up the male keyboard connector to clear the bracket and then plug it into the female keyboard connector.

After completing these steps the keyboard assembly show look as shown in the picture below.

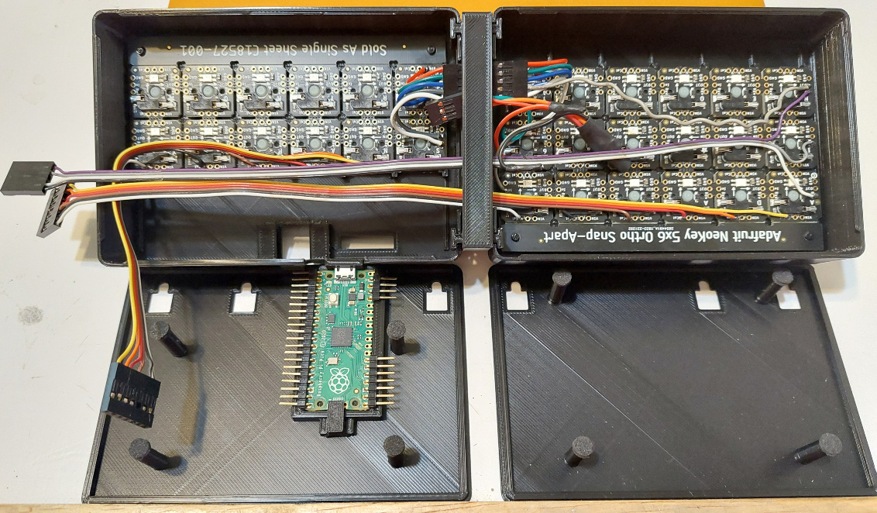
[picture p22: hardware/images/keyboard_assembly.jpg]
keyboard_assembly


### Display Assembly
Place the display board into the display front piece.  Make sure to first remove the plastic screen protector sheet that the display board comes shipped with!  The connector of the display board should align with the wider part of the vertcal frame and the screen should be flush to the forward surface of the display front piece.  

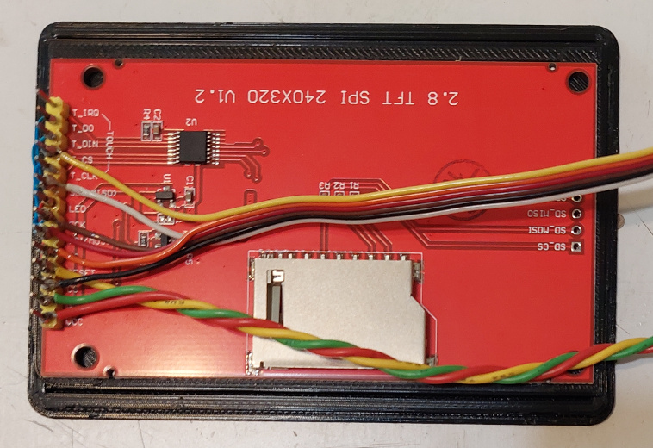
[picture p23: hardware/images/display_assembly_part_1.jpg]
display_assembly_part_1


Next, position the display front piece and the display body such the the bottom of both parts are adjacent to each other.  Fold the ribbon cable and power harness to the right so that they pass over the slot on the bottom the display body.  This should appear as shown in the picture below.  

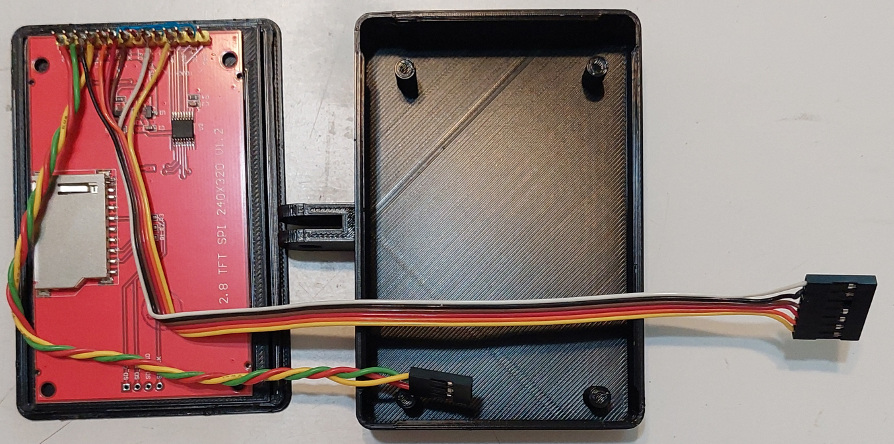
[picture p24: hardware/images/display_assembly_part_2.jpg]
display_assembly_part_2


Finally, flip the display front piece and display board over and thread the ribbon cable and power harness through the slot on the bottom of the display body.  Set the front piece on the display body and carefully press it until it snaps in place. DO NOT press on the display screen, as doing so could crack the display or touch screen, ruining it.  Once this is done, the display assembly should appear as in the picture below and is ready for final assembly.  Set it aside to start connecting cables to the Pico.

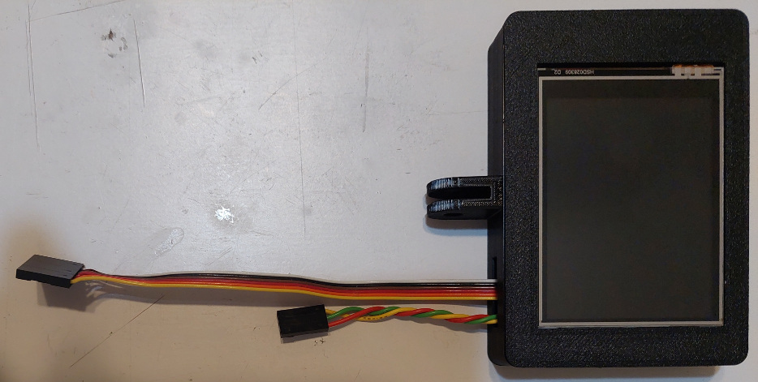
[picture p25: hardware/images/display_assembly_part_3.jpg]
display_assembly_part_3


### Inserting Connectors onto the Pico
Insert the female connector (four-pin shell) of the power wye cable on to pins 36 through 39 on the Pico.  Make sure that the 3.3V wire (orange) is connected to 3V3(OUT) (pin 36), the ground wire (green) is connected to GND (pin 38), and the 5V wire (red) is connected to VSYS (pin 39). Then, connect the column cable for the left keypad to pin 1 through pin 7 on the Pico.  The Column 0 (C0) wire should be connected to pin 1.  The picture below shows how the connections should look.

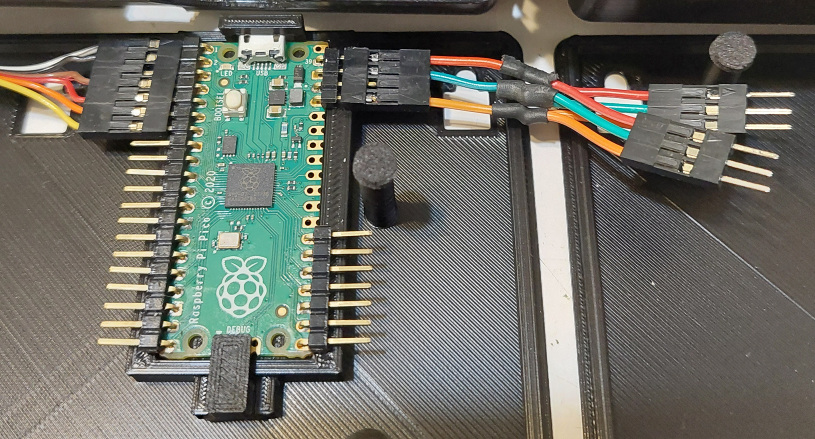
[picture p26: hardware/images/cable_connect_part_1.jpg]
cable_connect_part_1


Take the arm of the power wye that is below the other arm and bend it such that it can plug into the power harness of the right keypad assembly.  Make sure that 3.3V conductor (orange), Ground conductor (green), and 5V conductor (red) are matched up.  Otherwise a short or an over-voltage could be applied to a sensitive circuit.  The picture below shows how the connections should look.

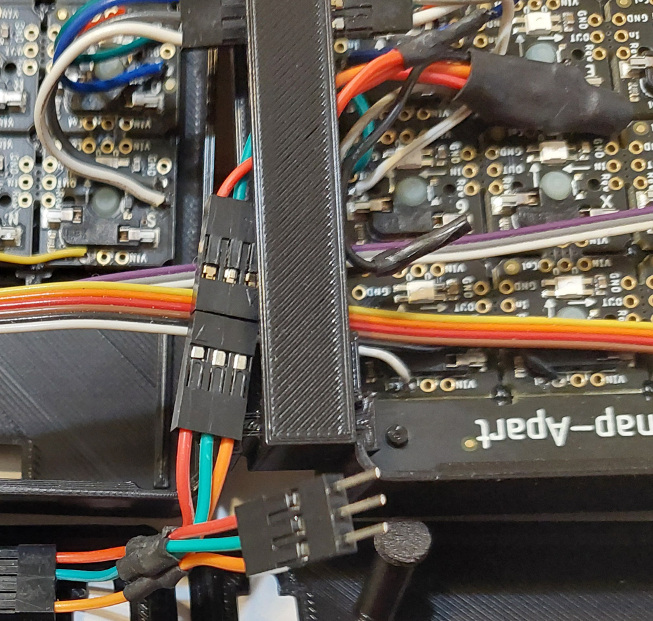
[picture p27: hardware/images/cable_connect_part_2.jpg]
cable_connect_part_2


Next, insert the column cable for the right keypad to pin 9 through pin 15 on the Pico. The Column 6 (C6) wire should be connected to pin 9.  Then, connect the row cable for the right keypad to pin 16 through pin 20 on the Pico. The Row 2 (R2) wire should be connected to pin 16 and the Neopixel low voltage (NP(LV)) wire should be connected to pin 20. The picture below shows how the connections should look.  

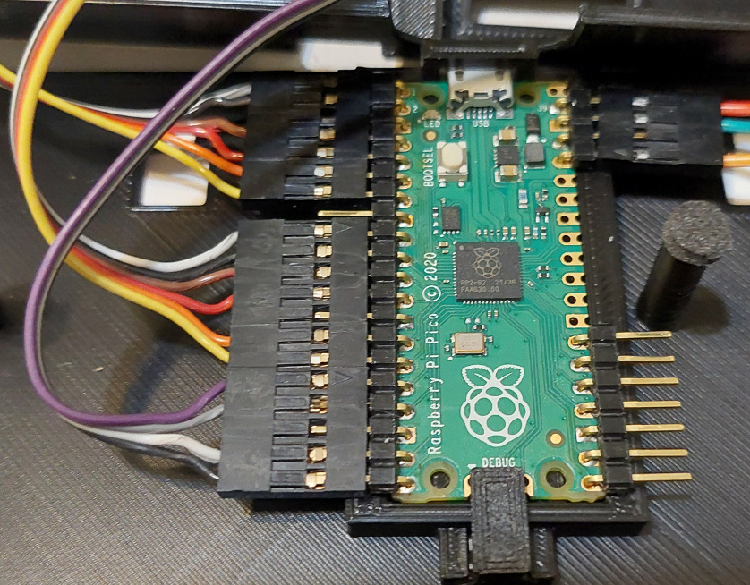
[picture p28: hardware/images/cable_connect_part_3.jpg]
cable_connect_part_3


Attach the display bracket to the display assembly by threading the fingers of the bottom of the display assembly between the fingers of the bracket.  Make sure that the bracket is aligned such that the hexagonal hole is on the right side of the display assembly.  Insert the display assembly's ribbon cable and power harness through the slot in the top of the left keypad assembly.  The picture belows shows how this should look.

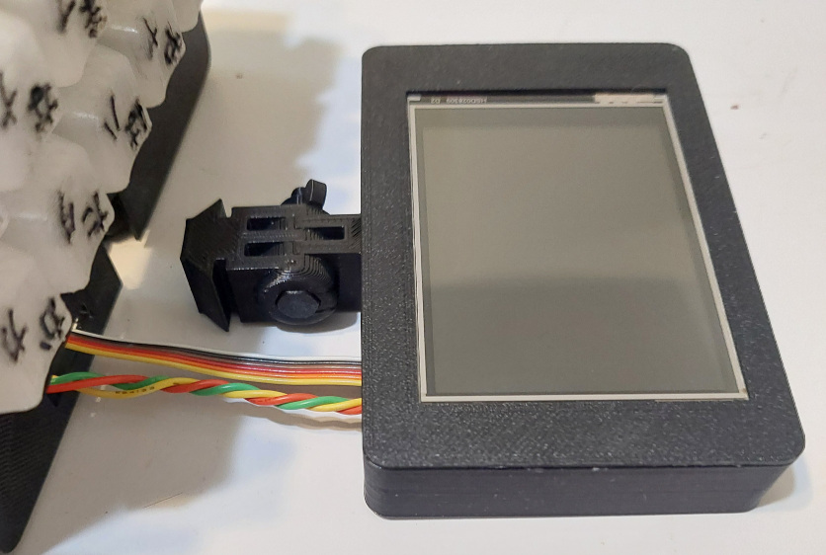
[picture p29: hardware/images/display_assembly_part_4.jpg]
display_assembly_part_4


Raise up the keyboard and insert the base of the display bracket into the dado slot on the left keypad.  Slide the bracket in until the back of the bracket flush with the back of the left keypad.  The picture belows shows how this should look.

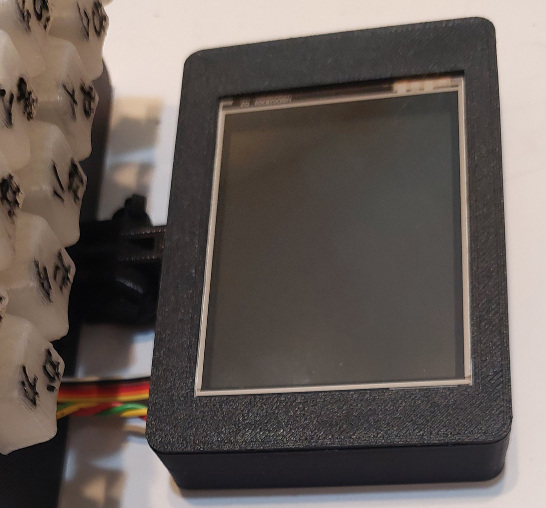
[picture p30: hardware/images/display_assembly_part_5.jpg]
display_assembly_part_5


Plug the connector of the display assembly's ribbon cable into pins 14 through 20 of the Pico.  Note that pin 18 will not have a connector pin.  Now plug the power harness of the display assembly into the remaining arm of the power wye.  Make sure that 3.3V conductor (orange/yellow), Ground conductor (green), and 5V conductor (red) are matched up.  Otherwise a short or an over-voltage could be applied to a sensitive circuit.  The picture below shows how the connections should look.

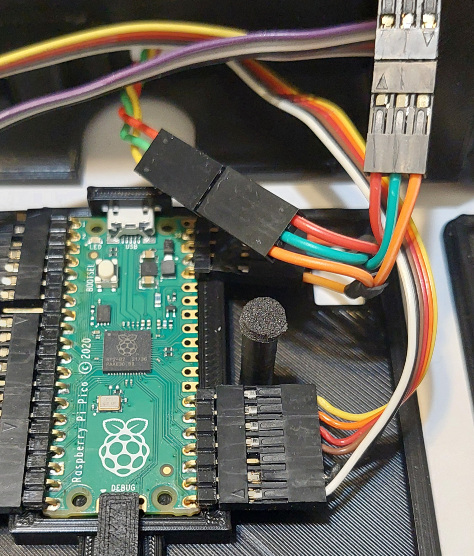
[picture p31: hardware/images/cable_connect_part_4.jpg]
cable_connect_part_4


### Attach Keyboard Bases and Feet
Now that the wiring is completed, the keyboard enclosure can be closed.  Place the right keyboard base onto the bottom of the right keyboard enclosure.  Make sure that the wiring and level shifter do not interfere with the keypad PCB supports pushing up against the bottom of the right keypad.  The keyboard base is a press-fit design, so it should pop into place without too much effort.  Now, fold over the left keyboard base, making sure that the wiring does not interfere with the keypad PCB support pushing up against the bottom of the left keypad.  Snap the left keyboard base into place, as was done with the right keyboard base. The assembly should appear as shown in the picture below.

keyboard_bases_attached

Attach the three keyboard feet by sliding the attachment pegs into the holes and sliding the feet into the slots.  If desired, the right and left keyboard feet can be glued into place.  It is not recommended to glue the center foot, as doing so would make it difficult to disassemble the keyboard for maintenance or modification.

keyboard_feet_attached

This concludes the hardware construction of the KanaChord Keyboard.  If not already done, program the Pico with the KanaChord software and put the keyboard to use!

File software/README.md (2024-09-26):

# KanaChord Plus Software
The software for KanaChord Plus was developed with open-source tools and libraries:
- Arduino Integrated Development Environment (Version 1.8.19),
- Wiring programming language (C++-ish),
- [Earle Philhower's RP2040 Arduino board support package](https://github.com/earlephilhower/arduino-pico),
- Libraries used:
   - [Arduino USB Keyboard Emulation](https://www.arduino.cc/reference/en/language/functions/usb/keyboard/),
   - [Mark Stanley's Arduino Keypad](https://github.com/Chris--A/Keypad),
   - [Adafruit Neopixel](https://github.com/adafruit/Adafruit_NeoPixel),
   - [Light and Versatile Graphics Library](https://lvgl.io/), version 8.4.

Note that the source code for the Keypad library has been slightly modified for the RP2040 and the file names have been renamed accordingly.  The output drive current for the keyboard polling lines has been set to 12 milliamps, which is the maximum for the RP2040.  It was found that the default setting of 4 milliamps provided insufficient current for the keyboard.

## Unicode Data
The file kana.h contains C++ arrays of 16-bit Unicode values for Kana (Hiragana and Katakana) characters, and some Chinese/Japanese/Korean punctuation and special characters.  The file kanji_md.h contains C++ structures of 16-bit Unicode values for Kanji characters.  Details on these Unicode blocks can be found in the following PDFs:
- [Official Unicode Consortium Hiragana code chart](https://www.unicode.org/charts/PDF/U3040.pdf)
- [Official Unicode Consortium Katakana code chart](https://www.unicode.org/charts/PDF/U30A0.pdf)
- [Official Unicode Consortium CJK Symbols and Special characters code chart](https://www.unicode.org/charts/PDF/U3000.pdf)
- [Official Unicode Consortium General Punctuation characters code chart](https://www.unicode.org/charts/PDF/U2000.pdf)
- [Official Unicode Consortium CJK Unified Ideographs code chart](https://www.unicode.org/charts/PDF/U4E00.pdf)

The arrays containing the Kana are grouped according Hiragana and Katakana character sets. Individual arrays represent unaugmented (base) characters and augmented characters, i.e., ten-ten, maru, and small (chiisai) characters. Each array is organized by ten 'consonants' (rows) and six 'vowels' (columns).  Special characters are also grouped according to Hiragana and Katakana character sets, although this results in most characters being duplicates in these sets. This was done to simplify the code used to access the arrays.  

The function getKanaUnicode(), defined in kbd_mgt.cpp, takes inputs of Kana mode, special character mode, shift mode, and index row and column to select a Unicode character value. If the selected Unicode value is 0x0000, then an illegal key combination has been selected.

## Compiling and Uploading the KanaChord Keyboard Software
First, start the Arduino IDE and click on Tools on the menubar and select Manage Libraries from the drop-down menu.  Install Earle Philhower's RP2040 Arduino board support package and the Arduino USB Keyboard emulation library.  Next, select Tools on the menubar and select Board from the drop-down menu.  Select 'Raspberry Pi RP2040 Boards' from the displayed cascade menu, and then 'Raspberry Pi Pico' from the next displayed cascade menu.

Now that Pico board support is in place, adjust the board parameters as shown in the picture below:  
KanaChord_Plus_Setup

Place the KanaChord Plus source files into a new directory named KanaChordPlus. Load KanaChordPlus.ino with the Arduino IDE. Click the Verify button to ensure that the KanaChord source code compiles successfully.  Compiling will take some time because of the size of the dictionary header files.  The compile status should be as shown in the picture below.  If compiling fails, check that all needed files and libraries are installed and the configuration is correct.

KanaChordPlus_Arduino_compile

Now, connect the Raspberry Pi Pico to the computer with a USB cable.  Click the Upload button to compile the KanaChord source code and upload the compiled binary to the Pico.  If the upload fails, make sure that the USB cable is securely connected to the Pico and the computer performing the programming. It may also be necessary to hold down the BOOTSEL button on the Pico while plugging the USB cable into the computer.

## Details on the KanaChord Plus software
The software in KanaChord Plus is much more complicated compared to that in the original [KanaChord Keyboard](https://github.com/maccody/KanaChord).  KanaChord only has to support the typing of Unicode for the Kana and a few special characters.  This is accomplished via a keyboard polling loop, a look-up table to match valid key combinations to Unicode, and sending the Unicode macro key sequence through a USB keyboard emulation to the host computer.  KanaChord Plus adds support for Kanji Unicode output, which is not trivial and requires some compromises.  The [dictionaries of Kanji and Japanese words](./dictionaries/README.md), the incremental IME (Input Method Editor), and the touch screen display, with [custom large font](./lvgl/README.md), all contributed to the added complexities.  

Fortunately, the Raspberry Pi Pico has hardware features that are not fully exploited by the KanaChord Keyboard.  One of two processing cores in the RP2040 processor are unused, as well as over 90% of the 2MB of flash ROM. The availability of two SPI (Serial Peripheral Interface) ports and additional general purpose I/O ports also enable the addition of extra capabilities required by the software in KanaChord Plus.

Having two cores in the RP2040 microcontroller enables hardware parallelism, dividing the processing load so that no single processor is overloaded.   In the Pico, Core 0 of the RP2040 is dedicated to interfacing with the USB interface.  In the KanaChord software, Core 0 was also used to poll the keypads.  It made sense to keep these functions together in KanaChord Plus.  Core 1 is dedicated to running the incremental IME, the display, and the touch screen, as their functions are tied closely together.

The subsections below describe various elements of the KanaChord Plus software.  Note that these descriptions are not detailed and do not cover every function in the code base.  There are some helper functions that are only inferred.  Also, the flowcharts may lack some details.  The best way to fully understand the code is to study the source code itself.

### Arduino setup() and loop() functions
High-level flowcharts for the Arduino setup() and loop() functions for Core 0 and setup1() and loop1() functions Core 1 are presented below:   
Software_Flowchart

Core 0 setup() processing initializes keypad polling, Neopixel configuration, and USB keyboard emulation.  Core 0 loop() processing manages keypad inputs, Neopixel states, and Unicode macro sequences outputs through the USB keyboard emulation.  A lot of the keypad processing performed by Core 0 involves determining whether a pressed key combination is valid or not.  If the combination is invalid, the Neopixels of the pressed key combination are turned red.  When the invalid key combination is released, the key colors are restored to their proper states.  If the combination is valid, a 16-bit Unicode, paired with a command flag, is sent to Core 1 via the Core 0-to-Core 1 FIFO.

Unicode characters are received from Core 1 via the Core 1-to-Core 0 FIFO. The Unicode characters are convered to Unicode macro sequences and placed into an output queue for output through the USB keyboard emulation.  The macro sequence sent is determined by a mode variable that is user-configurable and stored in non-volatile storage.  The macro sequences currently supported are for Microsoft Windows applications (e.g., MS Word, Wordpad, LibreOffice), Linux applications (e.g., LibreOffice, Firefox), and MacOS applications (functionality not tested yet).  The transmission rate of the macro code sequences are controlled to avoid sending garbled sequences to the host computer.

Core 1 setup() processing initializes the ILI9341 TFT display controller, the XPT2046 touch screen controller, the LVGL library, and the LVGL main interface.  Core 1 loop() processing manages the incremental IME, the LVGL display, and touch screen functions that allow the user to select Kanji and Japanese words based upon the Kana characters typed.  The simplicity of the loop belies the functionality performed by Core 1.  There are several complex functions performed by the incremental IME and the LVGL event handler executes callback functions that are described in subsequent sections.

Core 1 receives 16-bit Unicode and acommand flag via the the Core 0-to-Core 1 FIFO.  These are separated and the command flag determines how the Unicode code is inserted into the editor queue.  A command flag value of zero indicates that the Unicode is a Kana character.  This causes the Kana Unicode to be appended to the editor queue, unless the queue has been modified through selection of a Kanji or Japanese word.  In that case, the editor queue is first flushed of its contents, sent to Core 0 via the Core 1-to-Core 0 FIFO, and the new Kana Unicode is then placed into the emptied editor queue.  If there are Kana characters in the editor queue, the incremental IME functions are called to search the dictionaries for Kanji and Japanese words that correspond to the Kana characters.  The results are displayed for the user to select what is needed.

If the command flag associated with a received Unicode is a value of one, that the Unicode is a special character.  The character's treatment depends upon the special character.  If the special character is not a wide space, the Unicode is appended to the editor queue and the editor queue is flushed to Core 0.  If the character is a wide space, it is not appended to the editor queue and the editor queue is flushed to Core 0.  Normally, wide space characters do not appear within Japanese sentences.  If the editor queue is already empty, the wide space Unicode is placed in the editor queue and the queue is then flushed to Core 0.  This conditional behavior allows typing the wide space to force a Unicode sequence to be sent without adding a trailing special character, but still allows for the explicit output of wide space characters when needed.

### Functions for setting up the hardware
Flowcharts of the functions used to set up hardware are shown below.  The function kbd_setup() is called by setup(), while display_setup() and make_interface() are called by setup1().  
Hardware setup functions

Keypad initialization is performed primarily by the creation of an instance of the keypad class, found within kbd_mgt.cpp.  The remaining tasks performed by kbd_setup() are the initialization of the Neopixels in the Neokey kepads and changing the keypad debounce period from the default of 20 milliseconds to 40 millisecond.  When KanaChord Plus is first powered, it is set up for Hiragana input mode, so the Kana keys are set to green.  The shift keys and special characters keys are set to white.

The display_setup() function initializes non-volitale storage, if necessary.  This causes the touch screen calibration function to be called, which requires user input to accomplish.  If the non-volatile storage has already been initialized, then the existing touch screen calibration data is read.  This information is used to initialize the touch screen interface.  The LVGL software also require an initialization call prior to use.  In additional, the color palette for the KanaChord Plus interfaces are defined.

Once the LVGL software is initialized, make_interface() is called to create the main user interface using LVGL function calls.  This interface consists of a dropdown menu for character editor commands and user-selectable settings, the character editor window and the Kanji list window.  Currently, the menu provides two editor commands, which are: 1) delete the last character entered, and 2) delete all characters in the editor buffer.  The user-selectable settings are: 1) select the Unicode keyboard macro mode, and 2) perform the touch screen calibration.  A callback function for the dropdown menu is then initialized.  The text Editor window and the Kanji List window are then created.  Within the Kanji list window are two navigation buttons that are initially hidden, but are displayed when needed.  The callback functions for these buttons are then initialized.

### Functions for configuration settings
Five functions are used to manage the dropdown menu entries described in the previous section.  Three of the functions are callbacks that are invoked while interacting with the dropdown menu and supporting windows.  Two of the functions create the supporting windows.  The flowcharts for these functions are presented below.  
Configuration settings functions

The callback function settings_event_cb() is invoked when one of the entries on the settings dropdown menu are selected.  If the first menu entry is selected, the last character in the Editor window and Unicode queue are deleted.  Then, the content of the Kanji list window is cleared and a new Kanji List is generated using the remaining Kana characters in the Unicode queue as the key to search the dictionaries.  If the second menu entry is selected, all characters in the Editor window and Unicode queue are deleted.  The Kanji list window and the Kanji List are cleared, as there is no key available for a dictionary search.  

If the third menu entry is selected, a window is displayed using the function create_macro_select_window().  This new window allows the user to select the Unicode macro sequence that will be sent from KanaChord Plus to the host computer.  Once the sequence is selected, the user can Save the setting to non-volatile memory, invoking the save_macro_cb() function, or Cancel the change.  In either case, the window is dismissed using a callback function.  Note that callback functions, not described here, are created for the macro mode selection buttons.  

If the fourth menu entry is selected, a window is displayed by calling the function create_touch_calibration_window().  This window provides instructions to the user for performing a touch screen calibration.  When pressed, the Start Calibration button invokes the calibration_cb() function to run the touch screen calibration code.  Once completed, the new calibration parameters are saved to non-volatile memory.  Using the Cancel button closes the window.

### Functions that manage the Reading dictionaries
KanaChord Plus' incremental IME uses the Kana characters entered by the user as keys to search dictionaries of Kanji and Japanese words.   The results of the searches are displayed in the Kanji List window.  The user can then select which Kanji character or Japanese word will replace the Kana n the Editor window to convey the intended meaning, prior to sending that Unicode to the host computer.  The flowcharts for searching the dictionaries and creating the Kanji list data are presented below.  
Reading dictionary fuctions

When a new Kana character is added to the Kana queue, as displayed in the Editor window, the function build_kanji_list_data() is called.  Four dictionaries are searched, one each for Kunyomi, Onyomi, and Nanori readings, and one for Japanese words.  The corresponding functions calls are getKunyomiReading(), getOnyomiReading(), getNanoriReading(), and getDictionaryReading().  These four functions perform the same operations - generate a Murmur3 32-bit hash key and call the function get_reading(), but reference a different Binary Structured Tree (BST) for each dictionary.  The function get_reading() traverses the referenced BST recursively, searching with the key until either a match is found or a null pointer is encoutered.  If a match is found, the pointer to the matching reading structure is returned, otherwise a NULL pointer is returned.  For additional information on the dictionaries, consult the [KanaChord Plus dictionaries](./dictionaries/README.md) document in the dictionaries subdirectory.

Once are results are obtain from the four search operations, data for the Kanji list is generated.  The Kanji list is a list of pointers to different reading data, ordered according to the frequency (commonality) of the Kanji.  Note that Japanese words always appear first in the list, as they are common words that are likely to be used.  The goals is to present common Japanese words followed by Kanji characters that are ranked with most commonly-used Kanji first.

### Functions to display and manage Kanji lists
After the Kanji list data is generated from the four sets of dictionary data, it is displayed in the Kanji list window.  The user can then scroll through the list and select a Kanji or Japanese word.  The flowcharts for displaying, navigating, and selecting entries in the Kanji list window are presented below.  
Kanji display functions

The function build_kanji_list() prepares the Kanji List window by first calling the function clear_kanji_list() to remove the current Kanji entries displayed and hide the navigation buttons.  If the Kanaji data list has no content, then further processing is skipped.  If content is present, it is determined how how many elements the list has.  Some Kana readings yield many tens, even hundreds, of elements in the Kanji data list.  Displaying them all at once would make the scrolling interface slow to respond.  Consequently. no more than ten entries (Kanji and/or Japanese words) are presented in the Kanji List window at any one time.  As requied, paging buttons are display at the start and end of the abbreviated list.  The user can page to more and less commonly used Kanji accordingly.  The callback funcions kanji_nav_up_cb() and kanji_nav_dn_cb() are used to refresh the content of the Kanji list window, respectively.

Selection of a displayed Kanji or Japanese word is accomplished via the callback function kanji_list_cb().  Pressing of the button, positioned to the left of each Kanji List entry, is required to actually make a selection.  The right portion of each entry, displaying the English-language meaning of the Kanji or Japanese word, does not support selection, but enables the user to scroll up and down.  If the button pressed is associated with a Kanji's Onyomi or Nanori reading or a Japanese word, the character(s) replace the Kana content of the Editor window and their corresponding Unicodes in the Kana queue.  If the button pressed is associated with a Kanji's Kunyomi reading and there are no Okurigana for the reading, then the behavior is the same as the others.  Otherwise, the Okurigana window is displayed, as described in the next subsection.

### Functions to display and manage Okurigana lists
The Okurigana window is displayed whenever a Kanji is selected that has Okurigana associated with it.  The layout of this window is similar in style and usage as the Kanji list window.  The flowcharts for displaying and selecting entries in the Okurigana are presented below.  
Okurigana display functions

The function build_okurigana-window() first creates an LVGL window widget and populates the top banner with two buttons and a title.  The right button is a Cancel button.  When pressed, the Okurigana window is dismissed without making any changes to the Editor window or Kana queue.  The left button is decorated with the Kanji character only.  Pressing this button invokes the callback function kanji_only_cb(), which causes only the Kanji character to replace the Kana charcters in the Editor window and the Kana queue, followed by dismissing the Okurigana window.

Below the buttons and title bar, a list of Kanji entries are created.  The button on the left portion of each entry is a button showing the Kanji and its Okurigana.  The right portion of each entry shows the type of reading the Okurigana represents: simple (or standalone), prefix (leading other Kanji), or suffix (trailing other Kanji).  Pressing on the button of an entry invokes the callback function okuri_button_cb(), which causes the Kanji and Okurigana charactera to replace the Kana charcters in the Editor window and the Kana queue, followed by dismissing the Okurigana window.  As with the Kanji list window, the button at the left of the entry must be pressed for the replacement to occur.  The right portion of each entry allows the user to scroll the list as needed.

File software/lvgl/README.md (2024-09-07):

# LVGL Support
## Custom LVGL configuration file
The default LVGL configuration file (lv_conf.h) is set up for general development.  Most of the LVGL capabilitiies and widgets are enabled.  While this is convenient for general development, a lot of the capabilities within LVGL are not used by KanaChord Plus.  Disabling unused LVGL features frees up flash memory in the Raspberry Pi Pico.  This was done to alow increasing the number of Japanese words in the dictionary.

The LVGL configuration file in this directory was used when compiling KanaChord Plus.  To use it, copy it into the Arduino libraries directory (Arduino/libraries/) after installing the LVGL library.  If there is an lv_conf.h file already present, it is advised to change its name or move it to another directory to preserve its contents.

## Custom font generation
**NOTE: This information is provided in case a new custom font file needs to be created to support different characters or a different font style.  The custom font has aready been created and placed in the directory with the other souce code.**  
A custom font was created that contains the Kana characters, the set of 6,100+ Kanji currently supported, and a few special characters.  The [LVGL Font Converter](https://lvgl.io/tools/fontconverter) is used to generate a custom font file.  These are the values inserted into the fields of the converter.
- Name: KanaKanjiFont32
- Size: 32
- Bpp: 1 bit-per-pixel
- Fallback: <none>
- Output format: C file
- No options checked
- TTF/WOFF font: Noto_Sans_Mono_CJK_JP-Regular.otf
- Range: Taken from file kana_kanji_subset.txt

After the font file is downloaded, it needs to be modifed to compile properly with the Arduino project.  At the top of the file is the following block, which is a conditional define statement:
>#ifdef LV_LVGL_H_INCLUDE_SIMPLE  
>#include "lvgl.h"  
>#else  
>#include "lvgl/lvgl.h"  
>#endif  

Edit this block of code to have only one include statement:
>#include "lvgl.h"

Save the file and copy it into the directory containing the other source code before compiling.

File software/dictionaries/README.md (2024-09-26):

# KanaChord Plus dictionaries
Due to the nature of the Japanese language, providing Kanji support in KanaChord Plus was a challenging task!  Japanese is a phonetically limited language, with at least twelve (perhaps up to 21) distinct consonants and five distinct vowels.  The addition of mora (timing of pronunciation) and pitch accent add to the challenge.  The Kanji themselves are subject to interpretation, as the pronunciation of any particular Kanji can have Chinese readings (Onyomi), Japanese readings (Kunyomi), or readings assigned for name usage (Nanori).  As a consequence, there can be many Kanji and Japanese words that are homophones (sound the same), e.g., 花 (まな, hana) flower and 鼻 (はな, hana) nose, where pitch accent differentiates them otherwise.  This Wikipedia web page on [Japanese phonology](https://en.wikipedia.org/wiki/Japanese_phonology) provides an introduction for a deeper dive into the topic.  

The first challenge was providing a sufficiently diverse set of Kanji to support Japanese typing for most users.  There are currently over [fifty-thousand Kanji characters](https://en.wikipedia.org/wiki/Japanese_writing_system), although many are archaic and not in formal usage today.  Still, there are many thousands of Kanji that are in use and choosing which ones to support would be a daunting task.  Fortunately, as with other languages, some Kanji are used much more often than others, which provides a starting point for which Kanji to support.  The Japanese government mandates that all Japanese high school graduates learn the [常用漢字 (jōyō kanji)](https://en.wikipedia.org/wiki/J%C5%8Dy%C5%8D_kanji), or 'list of regular use Kanji' literally. These 2,136 Kanji provide a minimum standard for all Japanese to read and write.  Mulitple schollars have performed frequency analysis of Kanji to create more extensive lists of frequently-used Kanji.  The [Novel 5k](https://docs.google.com/spreadsheets/d/1l2MNM5OWznIRVm98bTCA1qPNAFnM48xJIyUPtchxyb0/edit?usp=sharing) spreadsheet and [Kanji Dict 2](http://www.edrdg.org/wiki/index.php/KANJIDIC_Project) XML document are two of these lists.  They were used to select 6,165 of the most common Kanji, with their associated meanings in English. This is the subset of Kanji that is currently supported by KanaChord Plus.  This Kanji subset should be suffcient for most users, possibly even at the collegiate level!  Note that the number of Kanji supported also drives the size of the Kanji font character set stored on the Pico.

Cross-referencing each reading to all associated Kanji requires 'inverting' the content of the Kanji Dict 2 XML document.  Kanji Dict 2 presents a structed list of thousands of Kanji, each with their relevant onyomi and kunyomi readings (in Katakana and Hiragana, respectively), nanori pronunciations (in Hiragana), and English meanings.  In addition, many kunyomi pronunciations have [Okurigana](https://en.wikipedia.org/wiki/Okurigana) (accompanying Hiragana after the Kanji) used to inflect adjectives and form verbs.  Sequentially processing each Kanji entry and tabulating it into each reading yields a table of readings with all associated Kanji and their English meanings.  There are three dictionaries generated, one each for onyomi, kunyomi, and nanori.  Note that the Okurigana are included in the Kunyomi dictionary to allow for direct selection rather than typing each Hiragana manually.

Beyond the Kanji are Japanese words in general, which can be composed of Hiragana, Katakana, Kanji, or a combination of all three.  It is possible to always type Kana characters, sometimes converting to Kanji, to then form individual Japanese words.  This can become tedious, though, especially when many of the same words are typed frequently.  Consequently, a forth dictionary is a collection of commonly used Japanese words.  Coincidentally, a number of common Japanese words are [Jukujikun](https://en.wiktionary.org/wiki/jukujikun), or 'compound character reading', which use Kanji characters to convey the meaning but their pronunciations are of Japanese origin.  An example is 今日 (kyō) or 'today', which would have a literal pronunciation of 'ima hi' or 'now day', based upon the Kanji used.

Finding extensive lists (more than a few thousand) of Japanese words containing frequency ranking, reading, and English meaning proved a bit difficult.  Ultimately three Core word spreadsheets (used for Anki decks), a list of official and unofficial Jukujikun words, and a frequency-ordered list of over 44,000 Japanese words were used.  Not surprising, but many of the most-common Japanese words consist of Kana only and are not included in the dictionary.  Of the remaining most-common words containing Kanji, 6,240 are in the current word dictionary, limited due to flash memory constraints (discussed below).

## Data structures forming the dictionaries
Several approaches were considered for storing the dictionaries in KanaChord Plus:
1. External flash card accessed through the Pico's SPI interface, using a flash card reader library - plenty of storage space, relatively slower access, and driver overhead.
2. Use part of the Pico's flash ROM as a flash drive, using a flash card reader library - Limited space (less than two megabytes) with file system overhead, about four times faster access with QSPI compared to SPI, but same driver overhead.
3. Create data structures representing the dictionaries that are stored in the flash ROM's program memory and accessed directly - Limited storage space (less than two megabytes), though more efficiently used, and fastest access possible, with no driver overhead.

The third option was chosen for this implementation of KanaChord Plus.  Speed in retrieving Kanji and English meaning data for the Kana currently typed will impact the responsiveness of the keyboard and the overall user experience.  It is anticipated that a future version of KanaChord Plus would use a board-compatible, RP2040-based microcontroller with 4MB, 8MB, or 16MB of flash ROM.  The recent (August 2024) introduction of the Raspberry Pi Pico 2 (RP2340-based microcontroller) with 4MB of flash ROM, would be a suitable replacement. The faster microcontroller could maintain or improve responsiveness, while providing extra flash ROM stoarge for either more Kanji, more Japanese words, or both!  

Several data structures were created to store the content of the four dictionaries and support rapid dictionary search based on the kana characters currently entered by the user.  The illustration below shows the relationship of these data structures.  
Data structure relationship

A [Balanced](https://en.wikipedia.org/wiki/Self-balancing_binary_search_tree) [Binary Search Tree (BST)](https://en.wikipedia.org/wiki/Binary_search_tree) is employed to quickly search each dictionary.  The sorted keys are hashes of Kana character sequences.  The hash algorithm used is [32-bit Murmur Hash version 3](https://en.wikipedia.org/wiki/MurmurHash) - the implementation code is found on the referenced Wikipedia page.  Each node of the BST is a data structure (bbt_node) that contains the following elements:   
- An unsigned 32-bit key that is a Murmur 3 hash of a reading (Kana character sequence).
- A pointer to a reading matadata structure  (reading_md* rmd) for containing the data related to the reading.
- Pointers to two child BST structures (bbt_node* lnode, bbt_node* rnode), which can be NULL if there is no child for a branch of the tree.

During the search down the BST of a dictionary, the submitted reading hash is compared to a structure's hash key.  If the submitted hash is either less than or greater than the hash key, the search continues using the structure referenced by the appropriate pointer.  If that pointer is null, then there is no match for the submitted reading hash.  If the submitted hash is equal to the key in the current BST structure, then the pointer to the associated reading metadata structure is returned.  

The reading metadata structure (reading_md) provides information regarding the Kanji and Japanese words associated with a reading.  The reading structure contains the following elements:
- An unsigned 16-bit value (len) indicating the number of Kanji and Okurigana or Japanese words associated with the reading (Kana character sequence).
- A pointer to an array of pointers to Okurigana or Japanese word/meaning metadata structures (okuri_md** olist).  For the Onyomi, Kunyomi, and Nanori dictionaries, this pointer will be set to the NULL pointer if there are no Okurigana for any of the Kanji referenced.  Doing this saves a lot of flash ROM storage that would otherwise be wasted.
- A pointer to an array of pointers to Kanji metadata structures (kanji_md ** klist).  For the Japanese word dictionary, this pointer will be set to the NULL value.  

Each reading metadata structure pointer returned from a directory search is accessed to build up a list of candidate Kanji and Japanese words that the user can choose from to replace the Kana character sequence that was entered.

The Okurigana / Japanese word metadata structure (okuri_md) has alternate uses depending upon which dictionary it is being used.  For the Onyomi, Kunyomi, and Nanori dictionaries, this metadata structure references any Okurigana associated with a Kanji.  There can be multiple Okurigana that are referenced.  For the Japanese word dictionary, this metadata structure references the Japanese word (combination of Kana and Kanji characters, encoded in UTF-8) and the meaning of the word in an English string.  There will be only one Japanese word and meaning string referenced.

The Okurigana / Japanese word metadata structure contains the following elements:
- An unsigned 8-bit value (len) indicating the number of Affix enumerations and Okurigana strings or Japanese word / English meaning strings.
- Pointer to array of Affix enumerations (affix_enum *alist).  For the Onyomi, Kunyomi, and Nanori dictionaries, the relevant enumerations are: none (simple reading without context) , prefix (prefix reading, placed before other Kanji), and suffix (suffix reading, placed after other Kanji).  For the Japanese word dictionary, the relevant enumerations are: jword (Japanese word in corresponding index of olist) and meaning (English meaning string in corresponding index of olist).  The content of alist is always one 'jword', followed by one 'meaning'.
- Pointer to array of Okurigana or Japanese words/meanings (char **clist).  All characters are UTF-8 encoded. For the Japanese word dictionary, the first string is always the Japanese word and the second string is always the meaning in English.

The Kanji metadata structure (kanji_md) references information about a Kanji associated with a reading.  The Kanji metadata structure contains the following elements:
- Unsigned 16-bit Unicode value (unicode) for the Kanji.
- Unsigned 16-bit value indicating rank order (rank) for the Kanji - lower value indicates common Kanji.
- Character pointer to string containing English meaning for the Kanji (char *meaning).

The rank value is used when generating a list of Kanji and Japanese words for the reading (Kana characters) provided.  The list is ordered such that Japanese word are listed first, followed by Kanji, with the more common listed first.

## Programmatic dictionary file generation

**NOTE: This section is only useful if one wants to understand how the various files are generated.  In this distribution, these files have already been generated and placed in their appropriate directories.  If you want to make changes to the files, then the Python script will need to be run and the files copied to the appropriate directories.**

The very large number of readings and their associated Kanji characters and Japanese words made it a big challenge to create all of the data structures for the four dictionaries.  It was decided to generate the dictionaries programmatically using a Python script.  This ensured consistency of data structure content and quick regeneration, when needed, to change or correct content.

The Python script, kana_kanji_dictionary.py has over 1400 lines of code with comments (fortunately!).  It was developed using Python 3.8.0.  The following Python libraries required by the script:
- XML (xml) - Extensible Markup Language library, particularly ElementTree support.
- Pandas (pandas) - Dataframe manipulation library.
- Itertools (itertools) - Advanced iteration function library.
- Murmur Hash version 3 (mmh3) - Murmur hash generation library.

The program is invoked from the command line as follows:  
`python kana_kanji_dictionary.py`

The following files are read by the Python script during processing:
- Novel 5K most common Kanji (Novel_5K.csv). Source: [Novel 5k](https://docs.google.com/spreadsheets/d/1l2MNM5OWznIRVm98bTCA1qPNAFnM48xJIyUPtchxyb0/edit?usp=sharing).
- Kanji Dict 2 (kanjidic2.xml) Source: [The KANJIDIC Project](http://www.edrdg.org/wiki/index.php/KANJIDIC_Project).
- List of Kana characters and their corresponding least-significant byte of Unicode values (kana_list.csv).
- Core 10K list of over ten thousand common Japanese words with pronunciations and meanings (Core10k.csv). Source: [Core 10000](https://core6000.neocities.org/10k/).
- Core 5K Frequency list of over five thousand of the most common Japanese words, with pronunciations and meanings (Core5kFrequencyMod3.csv).  Original CSV file has been modified to place single entries on each line.  Source: [Core 5000 Frequency](https://core6000.neocities.org/freq/).
- Core 6k list of over six thousand common Japanese words with pronunciations and meanings (Core6kMod.csv).  Original CSV file modified to place single entries on each line. Source: [Core 6000](https://core6000.neocities.org/).
- List of official and unofficial Jukujikun, or Japanese words with pronunciations that do not match the Kanji representing those words (jukujikun_mod.txt).  Original text file modified to combine official and unofficial lists. Source: [Kanjium - the ultimate kanji resource](https://github.com/mifunetoshiro/kanjium).
- 44492 Japanese Word frequency list (44492-japanese-words-latin-lines-removed.txt).  Source: [hingston/Japanese Github repo](https://github.com/hingston/japanese/blob/master/44492-japanese-words-latin-lines-removed.txt).

The following files are programatically generated by the Python script:
- kana_kanji_subset.txt - List of Unicode hexidecimal values to submit to [LVGL font converter](https://lvgl.io/tools/fontconverter).
- kanji_ms.h - Contains character strings for meanings of Kanji meaning in English.
- kanji_md.h - Data structures containing Kanji Unicode values, rank of commonality, and references to English meaning strings.
- onyomi.h - Data structures forming the dictionary of Onyomi (Chinese) readings for Kanji.
- kunyomi.h - Data structures forming the dictionary of Kunyomi (Japanese) readings for Kanji.
- nanori.h - Data structures forming the dictionary of Nanori (name) readings for Kanji.
- dictionary.h - Data structures forming the dictionary of common Japanese words containing Kanji.

Once generated, the C header files are copied to the directory containing the Arduino source code.  The file kana_kanji_subset.txt can be copied to the directory where the font file is located, but it is not strictly necessary.

A fairly high-level flow of the Python script, with line number references, is as follows:
- Import supporting libraries (lines 1 - 4) and define helper functions:
  - Perform iteration on lambda function to combine contiguous 16-bit Unicode values into ranges (lines 6 - 9).
  - Convert a byte value into bits (lines 11 - 16).
  - Reverse the bit order of a value (lines 18 - 24).
  - print_balanced_bst - Recursively print out a balanced BST to an opened file (lines 26 - 68).
- Define a list of common Kanji found in some Kanji lists (lines 70 - 83).
- Load in the Novel 5K and KANJIDICT 2 dictionaries (lines 85 - 94).
- Initialize dataframe (df1) to hold Kanji data (line 98).
- Iterate on each Kanji Dict 2 'character' element and perform the following (line 100):
  - Extract from the character element the Kanji Unicode, Kanji character, and frequency ranking, assigning a frequency rank if one is not present (lines 101 - 113).
  - Search for the Kanji character in the Novel 5K dictionary, extracting its rank if present, or assigning one if that Kanji is not present (lines 115 - 133).
  - Construct lists of meanings, Onyomi, Kunyomi, and Nanori associated with the Kanji character (lines 135 - 159).
  - Further processing is skipped for a Kanji if there are no readings found (lines 161 - 164).
  - Add a new row to dataframe df1 using the information collected for the Kanji (lines 166 - 169).
- Create a subset of dataframe df1 with only those rows with Novel 5K rank less than 10000.  Create two sortings on the subset: one based upon the Nover 5K rank in ascending order, the other based upon the Unicode value (line 174 - 187).
- Create a list of Kanji Unicode values, with contiguous Unicodes combined into ranges.  Then write some special Unicode characters, the Kana Unicode character ranges, and the Kanji list out to the text file kana_kanji_subset.txt (lines 188 - 212).
- Write all of the Kanji meanings as C character strings into a C header file, kanji_ms.h.  The naming of each string conincides with the associated Kanji's Unicode number.  An ordered list of Kanji Unicodes and their Novel 5K ranks is also created (lines 214 - 229).
- Write the collected Kanji data to a C header file, kanji_md.h.  Use the ordered list to to assure that the Kanji metadata structures are named according to the associated Kanji's Unicode (lines 231 - 263).
- Create dataframes for the Onyomi, Kunyomi, and Nanori cross-references (line 265 - 272).
- Interating on each row of dataframe df1, performing the following (line 275):
  - For each Onyomi in the row (line 277):
    - Determine whether it is a suffix or not (lines 278 - 283).
    - Determine whether the Onyomi is already in a row of the Onyomi data frame, appending the new data if it is, or adding a new row if it is not present (lines 289 - 305).
  - For each Kunyomi in the row (line 308):
    - Determine whether it is a prefix, suffix, or neither (lines 309 - 316).
    - Isolate Okurigana if present (lines 318 - 325).
    - Determine whether the Kunyomi is already in a row of the Kunyomi data frame, appending the new data if it is, or adding a new row if it is not present (lines 327 - 371).
  - For each Nanori in the row (line 374):
    - Isolate Okurigana if present (lines 377 - 383).
    - Determine whether the Nanori is already in a row of the Nanori data frame, appending the new data if it is, or adding a new row if it is not present (lines 385 - 402).
- For each row in the Onyomi dataframe (df2) (line 405):
  - Sort the Kanji for each reading by its frequency list in ascending order (lines 406 - 409).
  - Then sort the dataframe by the reading value in ascending order (line 412).
- For each row in the Kunyomi dataframe (df3) (line 415);
  - Sort the Kanji and associated Okurigana according to the frequency list in ascending order (line 416 - 431).
  - Then sort the dataframe by the reading value in ascending order (line 434).
- Sort the Nanori dataframe (df4) by the reading value in ascending order (line 445).
- Load in a list of mappings of Kana character to least-significat byte of their Unicode value and convert it into a Python dictionary (line 447 - 451).
- Output the Onyomi data structures to the file onyomi.h, first adding two new columns to the dataframe (lines 453 - 458).
  - Writing the structure typedefs to the file (lines 494 - 522)
  - Iterating on each row of sorted dataframe df2Sort (line 525):
    - Generate a Murmur3 hash key for the Kana reading (lines 526 - 536).
    - Add the Kana representation as an integer value and a byte string to the row for generating the Balanced BST later (lines 537 - 539).
    - Write out the Affix list, as a list of enumerations, and Okurigana metadata list as list of strings.  If all of the Affix values are 'none', this step is skipped (lines 541 - 562).
    - Write out the list of Kanji metadata structure references (lines 564 - 569).
    - Write out the Onyomi reading metadata structure referencing the list of Okurigana pointers, or NULL if none, and the list of Kanji metadata structure pointers (lines 571 - 576).
  - Write out the typedef of the Balanced BST structure to the file (lines 578 - 593).
  - Pull out the columns from the sorted dataframe df2Sort that are the Kana readings in integer form and byte string form and sort them according to the integer form in ascending order (lines 595 - 599).
  - Pull out the sorted Kana readings in byte string form and print out the Balance BST structures using the helper function print_balanced_bst (lines 597 - 603).
- Output the Kunyomi data structures to the file kunyomi.h, first adding two new columns to the dataframe (lines 609 - 614).
  - Writing the structure typedefs to the file (lines 648 - 676)
  - Iterating on each row of sorted dataframe df3Sort (line 679):
    - Generate a Murmur3 hash key for the Kana reading (lines 680 - 690).
    - Add the Kana representation as an integer value and a byte string to the row for generating the Balanced BST later (lines 691 - 693).
    - Write out the Affix list, as a list of enumerations, and Okurigana metadata list as list of strings.  If all of the Affix values are 'none', this step is skipped (lines 695 - 785).
    - Write out the list of Kanji metadata structure references (lines 787 - 793).
    - Write out the Kunyomi reading metadata structure referencing the list of Okurigana pointers, or NULL if none, and the list of Kanji metadata structure pointers (lines 796 - 804).
  - Write out the typedef of the Balanced BST structure to the file (lines 806 - 821).
  - Pull out the columns from the sorted dataframe df3Sort that are the Kana readings in integer form and byte string form and sort them according to the integer form in ascending order (lines 823 - 827).
  - Pull out the sorted Kana reading in byte string form and print out the Balance BST structures using the helper function print_balanced_bst (lines 830 - 833).
- Output the Nanori data structures to the file nanori.h, first adding two new columns to the dataframe (lines 838 - 843).
  - Writing the structure typedefs to the file (lines 877 - 905)
  - Iterating on each row of sorted dataframe df4Sort (line 908):
    - Generate a Murmur3 hash key for the Kana reading (lines 909 - 919).
    - Add the Kana representation as an integer value and a byte string to the row for generating the Balanced BST later (lines 920 - 922).
    - Write out the Okurigana metadata list as list of strings.  If there are no Okurigana data, this step is skipped (lines 924 - 987).
    - Write out the list of Kanji metadata structure references (lines 989 - 994).
    - Write out the Nanori reading metadata structure referencing the list of Okurigana pointers, or NULL if none, and the list of Kanji metadata pointers (lines 996 - 1001).
  - Write out the typedef for the Balanced BST structure to the file (lines 1003 - 1018).
  - Pull out the columns from the sorted dataframe df4Sort that are the Kana readings in integer form and byte string form and sort them according to the integer form in ascending order (lines 1020 - 1024).
  - Pull out the sorted Kana reading in byte string form and print out the Balance BST structures using the helper function print_balanced_bst (lines 1025 - 1030).
- Read in the Core 10K spreadsheet as a dataframe, dfC10K, and create a subset dataframe with just the Reading, Kanji, and Definition columns, dfPart1.  Add columns for 'Rank' and 'Source', setting all values to -1 and 'Core10K', respectively (lines 1038 - 1046).
- Read in the modified Core 5K Frequency spreadsheet as a dataframe, dfC5K (lines 1050 - 1052).
- Iterate on each row of the dataframe dfC5K, determining whether each word has Kanji that are in the subset of 6100+ most common Kanji (lines 1055 - 1064).
- Iterate on each row for the dataframe dfC5K, determining whether it is already in the dfC10K dataframe.  If it is, update the corresponding row of dataframe dfPart1 with the dfC5K rank value, which is the row number.  If is not matched, add a new row to dataframe dfPart1 with the new Kanji data and rank, with the source being 'Core5K' (lines 1066 - 1089).
- Copy the updated dataframe dfPart1 to a new dataframe dfPart2 (line 1092).
- Read in the modified Core 6K spreadsheet as dataframe, dfC6K (line 1095).
- Iterate on each row of the dataframe dfC6K, determining whether each word has Kanji that are in the subset of 6100+ most common Kanji (lines 1097 - 1106).
- Iterate on each row for the dataframe dfC6K, determining whether it is already in the dfPart1 dataframe.  If it is, do nothing, as there is no rank information available.  If is not matched, add a new row to dataframe dfPart2 with the new Kanji data, 'Rank' set to -1, and the 'Source' being 'Core6K' (lines 1109 - 1126).
- Copy the updated dataframe dfPart2 to a new dataframe dfPart3 (line 1092).
- Read in the modified Jukujikun readings file as dataframe, dfJuku (line 1132).
- Iterate on each row of the dataframe dfJuku, determining whether each word has Kanji that are in the subset of 6100+ most common Kanji (lines 1134 - 1143).
- Iterate on each row for the dataframe dfJuku, determining whether it is already in the dfPart2 dataframe.  If it is, do nothing, as there is no rank information available.  If is not matched, add a new row to dataframe dfPart2 with the new Kanji data, 'Rank' set to -1, and the 'Source' being 'Juku' (lines 1147 - 1165).
- Read in the 44492 japanese word file as dataframe, df44492 (line 1170).
- Iterate on each row for the dataframe df44492, determining whether it is already in the dfPart3 dataframe.  If it is, update rank information in the row(s) of dfPart3 according current row of df44492 plus 1.  There could be multiple results, so all must be updated.  If is not matched, no nothing (lines 1172 - 1181).
- Determine which rows in dfPart3 did not get ranked and drop them, creating the dictionary dataframe dfDict1 (lines 1183 - 118).
- Remove all word from dataframe dfDict1 that do not contain Kanji, creating another dictionary dataframe dfDict2 (line 1192 - 1206).
- Set an arbitrary upper limit for ranked words, maxRank (lines 1209 - 1229).
- Determine which words in dataframe dfDict2 exceed the maxRank.  Drop those words, creating the final dictionary dataframe dfDict3 (lines 1230 - 1232).
- Create an empty dataframe df5, with columns 'Reading', 'WordList', and 'MeaningList'. (line 1238).
- Iterate of the rows of dataframe dfDict3 (line 1241):
  - Determine whether the reading for the row in dataframe dfDict3 is already in dataframe df5 (line 1243).
    - If the reading is present, determine whether the word (called 'Kanji') is already associated with that reading.  If not, for that row in df5, append the word to the word list and the meaning to the meaning list.  If it is, just add the new meaning to the meaning list (lines 1246 - 1258).
    - If the reading is not present, add a new row to dataframe df5 with the reading, forming new word list and meaning list (lines 1259 - 1266).
- Sort dataframe df5 according to the reading in ascending order, creating a new dataframe, df6Sort.

- Output the Dictionary data structures to the file dictionary.h, first adding two new columns to the dataframe df6Sort (lines 1271 - 1276).
  - Writing the structure typedefs to the file (lines 1309 - 1337)
  - Iterating on each row of sorted dataframe df6Sort (line 1340):
    - Generate a Murmur3 hash key for the Kana reading (lines 1343 - 1352).
    - Add the Kana representation as an integer value and a byte string to the row for generating the Balanced BST later (lines 1353 - 1355).
    - Iterate on each element of the word list (line 1359):
      - Write out the Affix enumeration list, which has only the values 'jword', followed by 'meaning' (lines 1360 - 1362).
      - Write out the Okurigana list, which has only the Japanese word in UTF-8 characters, followed by the meaning string (lines 1363 - 1378).
      - Write out the Okurigana metadata that references the above Affix and Okurigana lists (lines 1379 - 1381).
    - Write out the list of Okurigana metadata pointers (lines 1384 - 1391).
    - Write out the Dictionary reading metadata structure referencing the list of Okurigana pointers.  The Kanji metadata list pointer is set to NULL (lines 1392 - 1394).
  - Write out the typedef for the Balanced BST structure to the file (lines 1396 - 1411).
  - Pull out the columns from the sorted dataframe df6Sort that are the Kana readings in integer form and byte string form and place them in a dataframe df6Sub.  Sort df6Sub according to the integer form in ascending order (lines 1413 - 1417).
  - Pull out the sorted Kana reading in byte string form and print out the Balance BST structures using the helper function print_balanced_bst (lines 1419 - 1421).

**If you have made it this far, I congratulate you!**

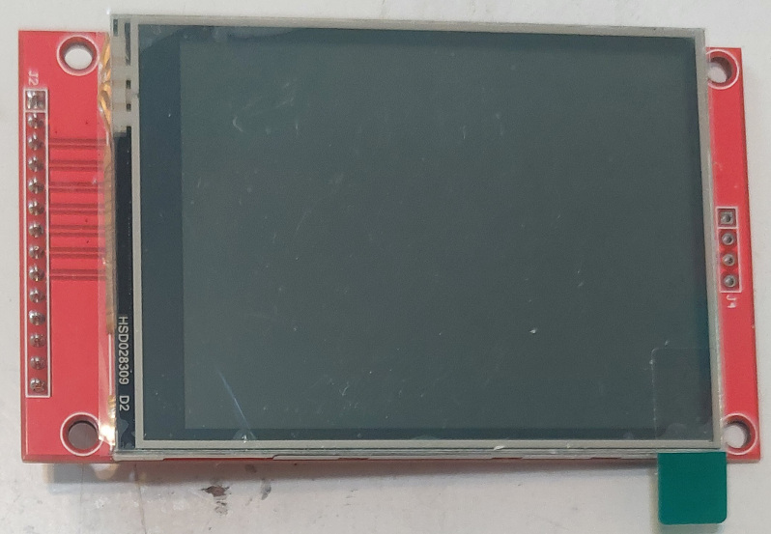
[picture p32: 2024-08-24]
hardware/images/display_front.jpg

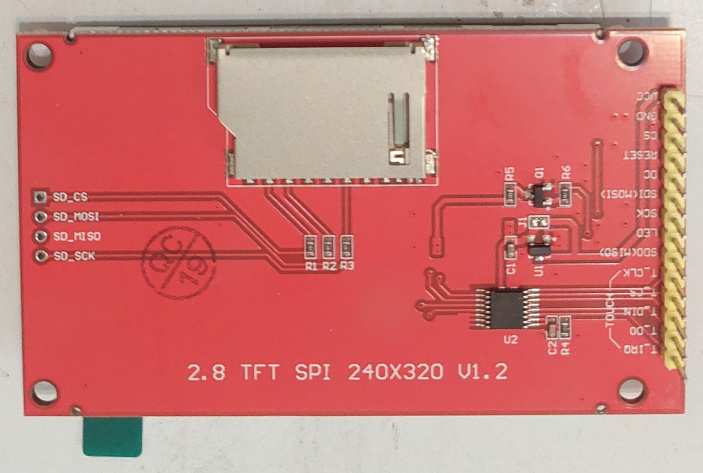
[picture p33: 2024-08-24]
hardware/images/display_back.jpg

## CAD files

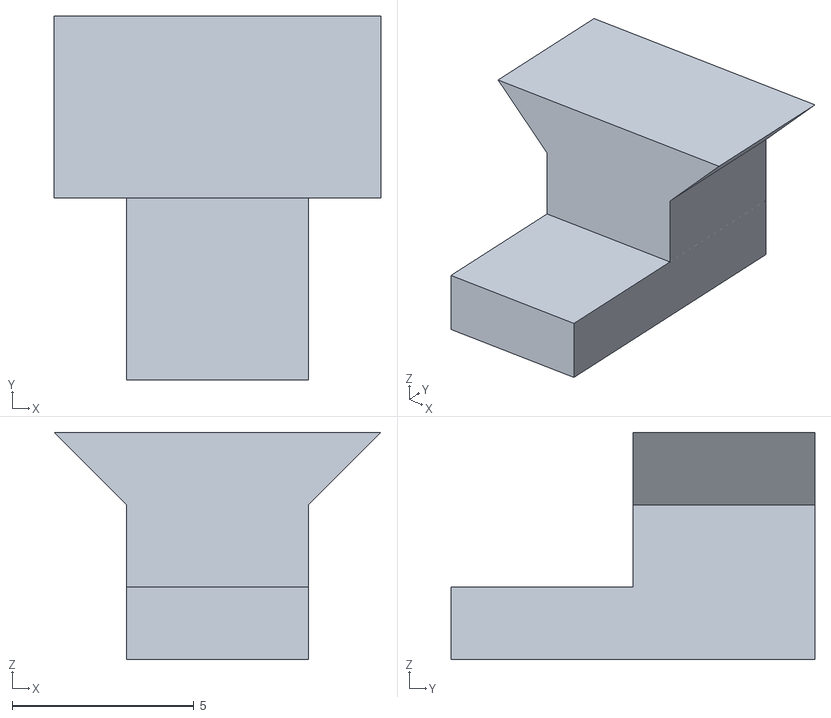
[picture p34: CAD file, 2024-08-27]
hardware/KanaChordPlus-pico_clip.stl
8.99 x 10.0 x 6.25

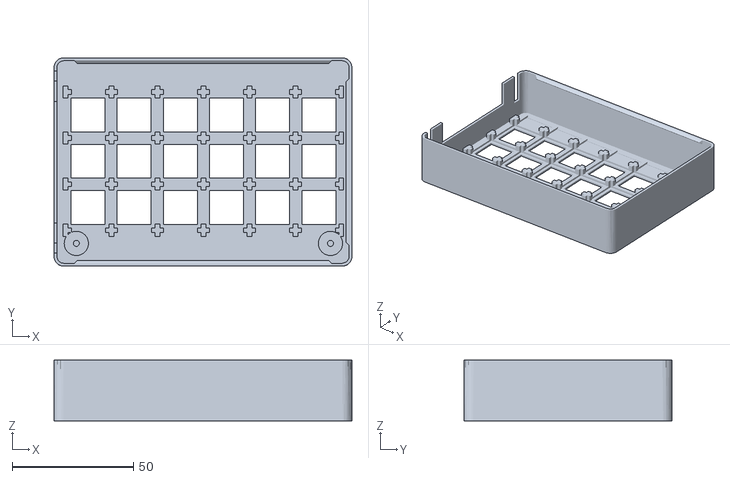
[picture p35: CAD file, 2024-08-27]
hardware/KanaChordPlus-keycase-right.stl
123.0 x 86.0 x 25.0

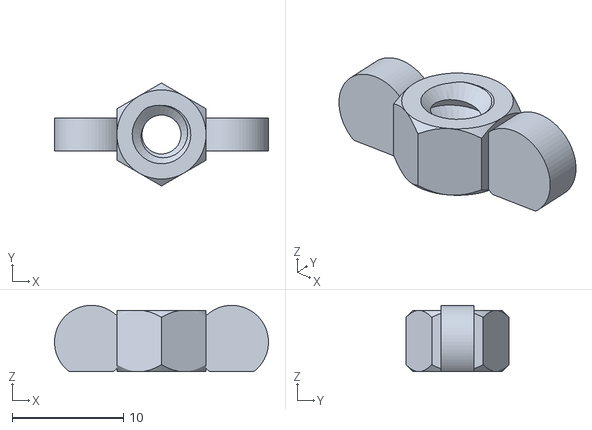
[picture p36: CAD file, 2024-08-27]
hardware/KanaChordPlus-wingnut.stl
19.2 x 9.24 x 5.95

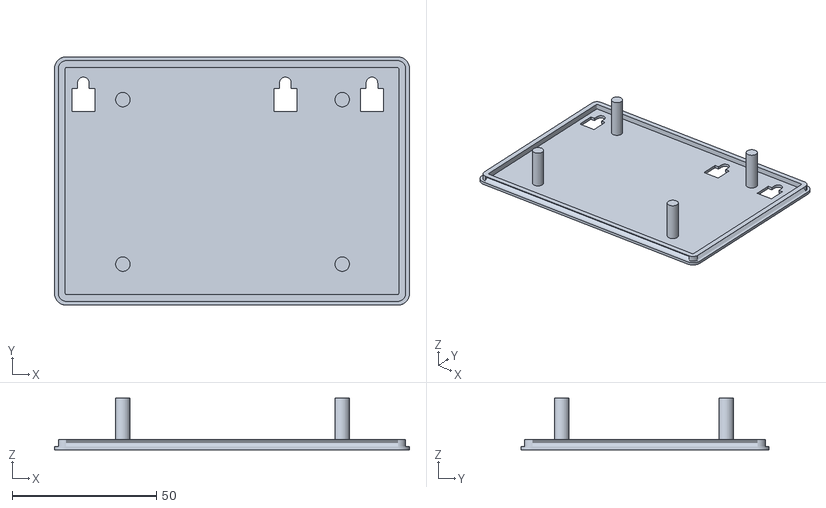
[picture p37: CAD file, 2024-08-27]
hardware/KanaChordPlus-keybase-right.stl
123.0 x 86.0 x 18.0

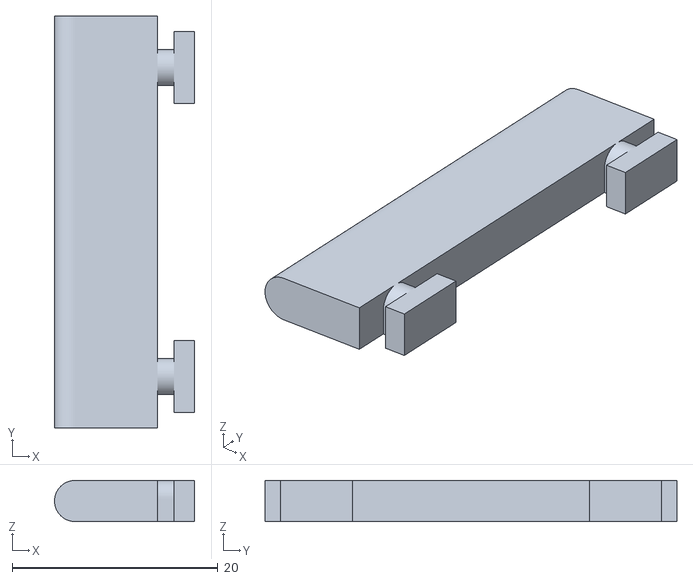
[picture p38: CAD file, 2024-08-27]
hardware/KanaChordPlus-foot.stl
13.6 x 40.0 x 4.00

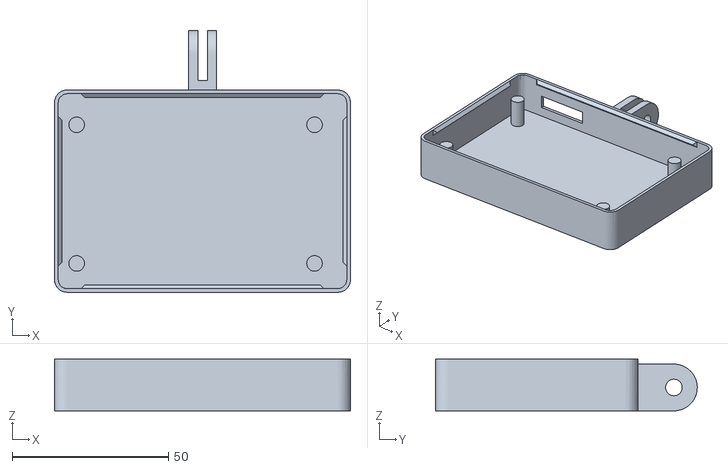
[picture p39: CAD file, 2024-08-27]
hardware/KanaChordPlus-display_case.stl
94.8 x 83.8 x 16.6

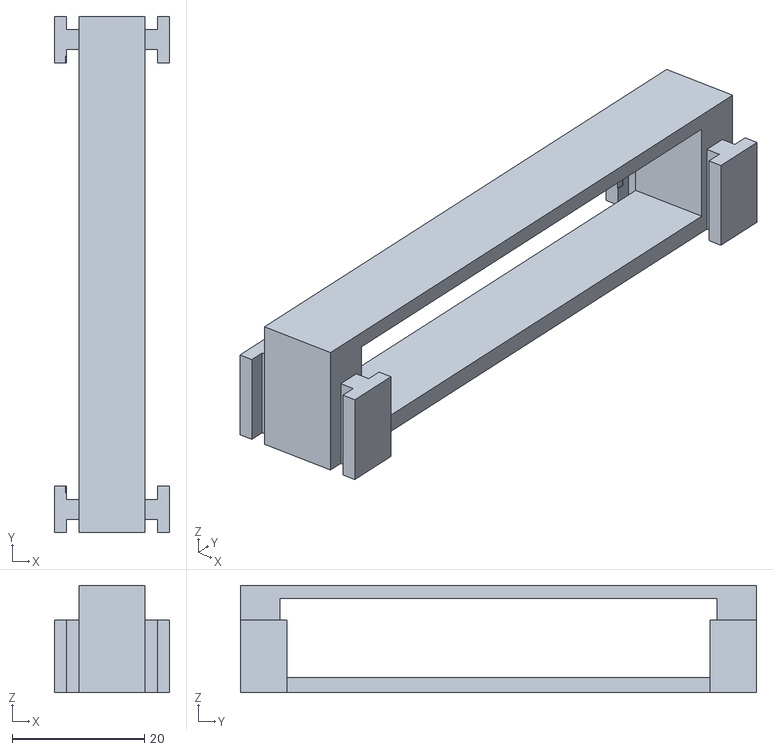
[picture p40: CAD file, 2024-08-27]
hardware/KanaChordPlus-casebridge.stl
17.4 x 78.0 x 16.2

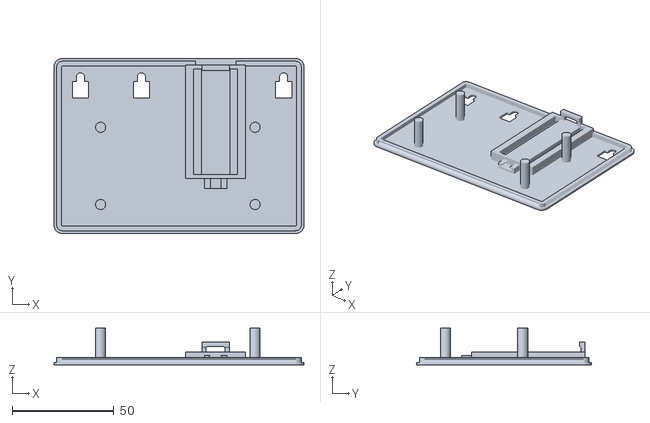
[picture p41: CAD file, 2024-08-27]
hardware/KanaChordPlus-keybase-left.stl
123.0 x 86.0 x 18.0

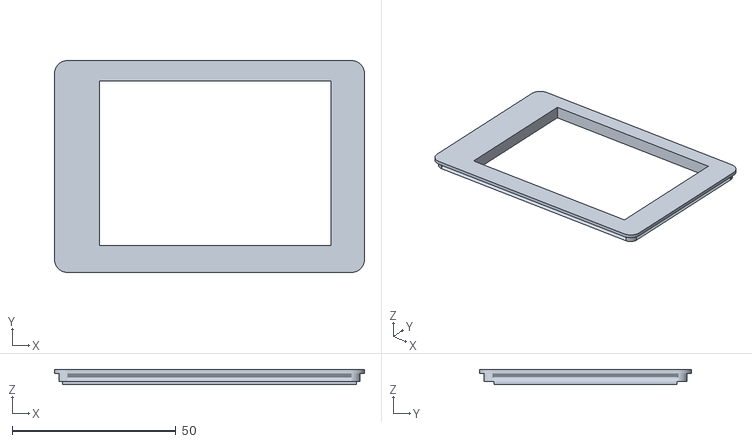
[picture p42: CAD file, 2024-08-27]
hardware/KanaChordPlus-display-front.stl
94.8 x 64.8 x 4.51

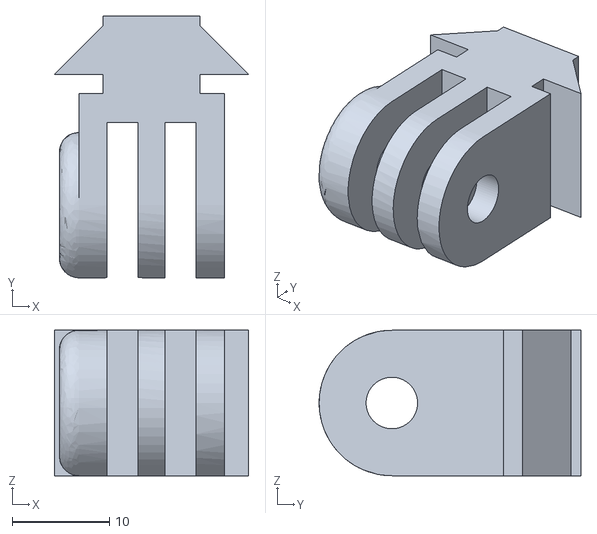
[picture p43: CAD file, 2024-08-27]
hardware/KanaChordPlus-display_bracket.stl
20.0 x 27.0 x 15.0

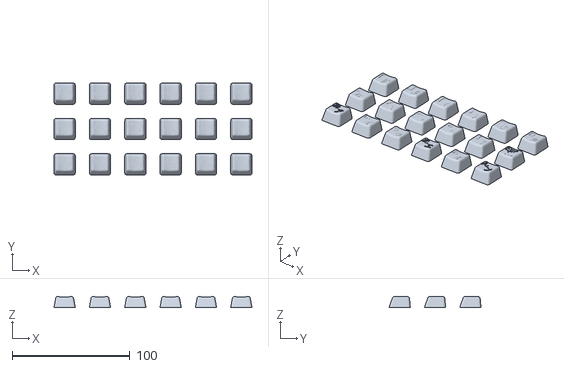
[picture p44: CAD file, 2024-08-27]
hardware/KanaChordPlus_RightHandKeys.stl
168.1 x 78.1 x 9.45

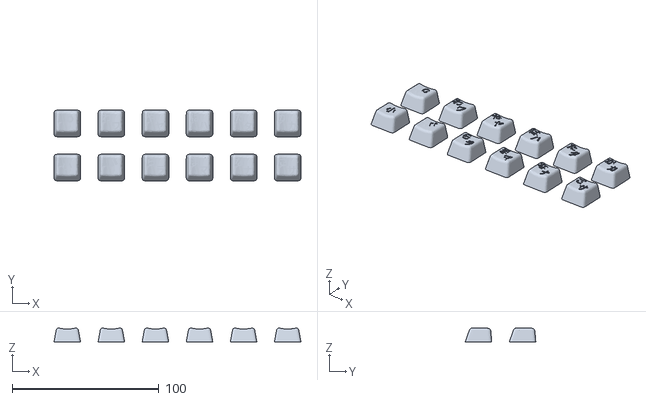
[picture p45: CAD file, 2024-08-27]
hardware/KanaChordPlus_LeftHandKeys.stl
168.1 x 48.1 x 9.45

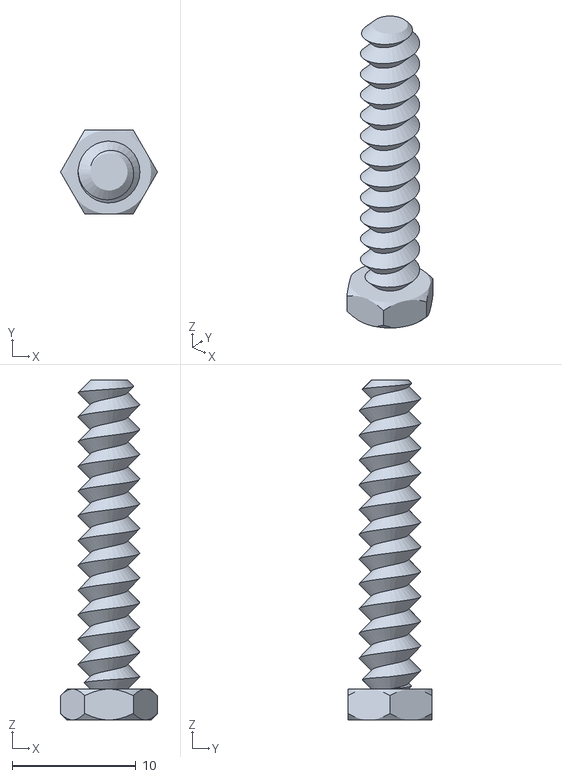
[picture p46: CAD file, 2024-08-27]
hardware/KanaChordPlus-bolt.stl
7.85 x 6.80 x 27.5

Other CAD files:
hardware/KanaChordPlus-keycase-left.stl

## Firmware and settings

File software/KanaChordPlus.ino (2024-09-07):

/* KanaChordPlus.ino */
/**
This file is part of KanaChordPlus Keyboard.
 Copyright (C) 2024 Mac A. Cody

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
 You should have received a copy of the GNU General Public License
 along with this program.  If not, see <http://www.gnu.org/licenses/>.
**/

#include <Keyboard.h>
#include "display.h"
#include "kdict.h"
#include "kbd_mgt.h"


/**
 * Inter-core communications consists of unsigned, 32-bit values that are pushed onto a
 * fifo by one core and removed from the fifo by the other core.
 * 
 * In this application, data transfers from Core 0 to Core 1 have the bits partitioned
 * as follows:
 * 24-bit Unicode value: bits 0 - 23
 * 8-bit command value: bits 24 - 31
 * The following command values have been defined:
 * 0x00 - If Unicode queue is unmodified, append Unicode to end of queue and process 
 * with the Incremental Input Method Editor (IIME).  If the Unicode queue is modified 
 * (contains Kanji), send the queue content, clear the queue, add the Unicode to the
 * queue, and process with the IIME.
 * 0x01 - Add Unicode to queue, if it is not an Ideographic Space (0x3000), or if the 
 * queue is empty. Then send the queue content.
 * 
 * Data transfers from Core 1 to Core 0 currently utilize only lower 16 bits, which
 * are the Unicode value of the character sent to the computer as a macro sequence.
 */

// Supporting data and test sequences of Hirigana characters and command codes.
// These are to be removed when no longer needed.

/**
 * Kana, Kanji, and CJK symbol characters are converted into keyboard sequences
 * placed in a queue for eventual output to the computer via the USB HID.  As
 * a sequence characters is pulled from the queue and sent to the USB port, a 
 * timer may be set up to delay the transmission of the next sequence character.
 */
#define USB_QUEUE_SIZE 100
#define USB_WAIT_TIME 20
char usbQueue[USB_QUEUE_SIZE];
uint16_t inIdx, outIdx;
unsigned long lastSentTime;

/**
 * Function: insertUSBQueue - Insert USB sequence character into USB queue.
 * The input pointer is incremented, being wrapped back to zero the end
 * of the queue is reached.
 * Input: usbValue - USB sequence character.
 * Output: None.
 */
void insertUSBQueue(char usbValue) {
  usbQueue[inIdx++] = usbValue;
  if (inIdx >= USB_QUEUE_SIZE) {
    inIdx = 0;
  }
}

/**
 * Function: loadUSBQueue - Convert Unicode character value into a USB
 * character sequence and place them into the USB queue for eventual
 * transmission to the USB port.  The sequence formed depends upon the
 * Unicode Mode currently in effect.
 * Input: ucsValue - 16-bit Unicode value.
 * Output: None.
 */
void loadUSBQueue(uint16_t ucsValue) {
  // Convert Unicode value to ASCII by first isolating each nybble.
  // Add ACSII '0' (48) if nybble less than 10, otherwise add ten
  // less than ASCII 'a' (97).
  uint8_t n0 = uint8_t (ucsValue >> 12);
  n0 = n0 < 10 ? 48 + n0 : 87 + n0;
  uint8_t n1 = uint8_t ((ucsValue >> 8) & 0x000f);
  n1 = n1 < 10 ? 48 + n1 : 87 + n1;
  uint8_t n2 = uint8_t ((ucsValue >> 4) & 0x000f);
  n2 = n2 < 10 ? 48 + n2 : 87 + n2;
  uint8_t n3 = uint8_t (ucsValue & 0x000f);
  n3 = n3 < 10 ? 48 + n3 : 87 + n3;
  
  switch (unicodeMode) {
    case 0:
      // Macro sequence for MS Windows.
      // Insert Unicode characters in USB queue.
      insertUSBQueue((char) n0);
      insertUSBQueue((char) n1);
      insertUSBQueue((char) n2);
      insertUSBQueue((char) n3);
      // Insert character to request KEY_LEFT_ALT in USB queue.
      insertUSBQueue('A');
      // Insert character 'x' in USB queue.
      insertUSBQueue('x');
      // Insert character to RELEASE_ALL in USB queue.
      insertUSBQueue('R');
      break;
    case 1:
      // Macro sequence for Linux.
      // Insert character to request KEY_LEFT_SHIFT in USB queue.
      insertUSBQueue('S');
      // Insert character to request KEY_LEFT_CTRL in USB queue.
      insertUSBQueue('C');
      // Insert character 'u' in USB queue.
      insertUSBQueue('u');
      // Insert Unicode characters in USB queue.
      insertUSBQueue((char) n0);
      insertUSBQueue((char) n1);
      insertUSBQueue((char) n2);
      insertUSBQueue((char) n3);
      // Insert character to RELEASE_ALL in USB queue.
      insertUSBQueue('R');
      break;
    case 2:
      // Macro sequence for MacOS (TBD).
      // Insert character to request KEY_OPTION in USB queue.
      // The Option key the same as the Left ALT key.
      insertUSBQueue('A');
      // Insert Unicode characters in USB queue.
      insertUSBQueue((char) n0);
      insertUSBQueue((char) n1);
      insertUSBQueue((char) n2);
      insertUSBQueue((char) n3);
      // Insert character to RELEASE_ALL in USB queue.
      insertUSBQueue('R');
      break;
  }
}

/**
 * Function: sendUSBValue - Send USB character from USB queue
 * to the computer via the USB HID device.
 * Input: None.
 * Output: None.
 */
void sendUSBValue(void) {
  char usbValue;

  // If the previous USB value sent requires a wait period,
  // do not do anything until the wait period has exceeded.
  if (millis() - lastSentTime > USB_WAIT_TIME) {
    // If there are USB values in the queue, take one out
    // of the queue and process it.
    if (outIdx != inIdx) {
      usbValue = usbQueue[outIdx++];
      if (outIdx >= USB_QUEUE_SIZE) {
        outIdx = 0;
      }

      switch (usbValue) {
        case 'A':
          Keyboard.press(KEY_LEFT_ALT);
          // Introduce wait for 20 milliseconds.
          lastSentTime = millis();
          break;
        case 'C':
          Keyboard.press(KEY_LEFT_CTRL);
          // Introduce wait for 20 milliseconds.
          lastSentTime = millis();
          break;
        case 'R':
          Keyboard.releaseAll();
          // Introduce wait for 20 milliseconds.
          lastSentTime = millis();
          break;
        case 'S':
          Keyboard.press(KEY_LEFT_SHIFT);
          // Introduce wait for 20 milliseconds.
          lastSentTime = millis();
          break;
        case 'x':
          Keyboard.press('x');
          // Introduce wait for 20 milliseconds.
          lastSentTime = millis();
          break;
        default:
          Keyboard.write(usbValue);
          break;
      }
    }
  }
}

// Core 0 setup and loop functions.
void setup() {
  rp2040.idleOtherCore();
  // Initialize the USB keyboard emulation.
  Keyboard.begin();
  kbd_setup();
  inIdx = 0;
  outIdx = 0;
  lastSentTime = 0;
  rp2040.resumeOtherCore();
}

void loop() {
  uint16_t ucsValue;

  // Obtain key data from keypads.
  uint32_t kanaValue = kbd_process();
  // This FIFO call WILL be used to send character data to Core 1.
  if (kanaValue != 0x00000000) {
    rp2040.fifo.push((uint32_t) kanaValue);
  }
  
  if (rp2040.fifo.available() > 0) {
    ucsValue = (uint16_t) (rp2040.fifo.pop() & 0x0000ffff);
    loadUSBQueue(ucsValue);
  }

  sendUSBValue();
}

uint16_t ucsQueue[10];
uint16_t queueIdx;
bool queueModified;

/**
 * Function: clear_input_queue() - Clear Unicode character queue.
 * Input: None.
 * Output: None.
 */
void clear_input_queue(void) {
  queueIdx = 0;
  queueModified = false;
}

/**
 * Function: decrement_input_queue - Reduce Unicode character queue by
 * one character, if there are characters in the queue.
 */
void decrement_input_queue(void) {
  if (queueIdx > 0) {
    queueIdx--;
    clear_kanji_list();
    build_kanji_list_data(ucsQueue, queueIdx);
    // Set external variable indicating beginning viewpoint of the displayed Kanji list.
    listStart = 0;
    build_kanji_list();
  }
}

/**
 * Function: kana_to_kanji() - Replaces Kana Unicode values with
 * a selected Kanji Unicode value.
 * Input: Kanji Unicode character value.
 * Output: None.
 */
void kana_to_kanji(uint16_t *ucsList, uint16_t len) {
  uint16_t i;
  for (i = 0; i < len; i++) {
    ucsQueue[i] = ucsList[i];
  }
  queueIdx = i;
  queueModified = true;
}

/**
 * Fuction: send_queue() - Send content of Unicode queue to Core 0.
 * Input: None.
 * Output: None.
 */
void send_queue(void) {
  // Transfer content of ucsQueue to RP2040 FIFO to send to Core 0.
  for (int i = 0; i < queueIdx; i++) {
    rp2040.fifo.push((uint32_t) ucsQueue[i]);
  }
  clear_input_queue();
  clear_kanji_list();
  clear_text();
}

// Core 1 setup and loop functions.
void setup1() {
  delay(10);
  queueIdx = 0;
  queueModified = false;
  display_setup();
  // Construct the main components of the interface.
  make_interface();
}

void loop1() {
  uint32_t ucsValue;
  uint8_t cmdValue;

  if (rp2040.fifo.available() > 0) {
    ucsValue = rp2040.fifo.pop();
    cmdValue = (uint8_t) (ucsValue >> 24);
    ucsValue = (ucsValue & 0x0000ffff);

    if (cmdValue) {
       if ((ucsValue != 0x3000) || (queueIdx == 0)) {
         ucsQueue[queueIdx++] = (uint16_t) ucsValue;
       }

       send_queue();
    } else {
      if (queueModified) {
        send_queue();
      }

      ucsQueue[queueIdx++] = (uint16_t) ucsValue;
      // Insert the kana character into the display after the last character
      // currently displayed in the textarea widget.
      insert_kana_char((uint16_t) ucsValue);
      build_kanji_list_data(ucsQueue, queueIdx);
      // Set external variable indicating beginning viewpoint of the displayed Kanji list.
      listStart = 0;
      build_kanji_list();
    }
  }

  display_handler();
}

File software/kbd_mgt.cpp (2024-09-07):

/* kbd_mgt.cpp */
/**
This file is part of KanaChordPlus Keyboard.
 Copyright (C) 2024 Mac A. Cody

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
 You should have received a copy of the GNU General Public License
 along with this program.  If not, see <http://www.gnu.org/licenses/>.
**/

#include <Arduino.h>
#include "Keypad2040.h"
#include <Adafruit_NeoPixel.h>
#include "kana.h"
#include "kbd_mgt.h"

//#define DEBUG 1

/*
 * The Adafruit Neokey board, which has five rows and six columns,
 * is broken between the third and fourth rows and set up as a
 * keyboard with three rows and twelve columns.  Note that the
 * left-most six columns only has two rows.
*/
#define ROWS 3
#define COLS 12
// Different key groupings are differentiated by the value of the
// most-significant nybble.
#define CONSO_KEY 0
#define SHIFT_KEY 1
#define VOWEL_KEY 2
#define SPECL_KEY 3
/*
 * Rather than containing ASCII characters, the key array contains
 * codes for each key group.  The most significant nybble contains
 * the key group:
 * 0x0 - Consonant keys
 * 0x1 - Shift keys
 * 0x2 - Vowel keys
 * 0x3 - Special keys
 * 
 * The least sigificant nybble contains the indexing for the key group:
 * Consonant keys - Index is row of table.  Note: index of 0 implies vowels.
 * Shift keys - Index values: 0 = none, 1 = ten-ten, 2 = maru, 4 = chiisai.
 * Vowel keys - Index is column of table.
 * Special keys - Bits 0 - 3 for column index, bit 4 is row index.
  */
char keys[ROWS][COLS] = {
  {0x14,0x11,0x08,0x06,0x04,0x02,0x20,0x21,0x22,0x23,0x24,0x25},
  {0x12,0x09,0x07,0x05,0x03,0x01,0x30,0x31,0x32,0x33,0x34,0x35},
  {0x00,0x00,0x00,0x00,0x00,0x00,0x38,0x39,0x3a,0x3b,0x3c,0x3d},
};

// Arduino pins for the rows of the keypad.  RP Pico GPIO pin numbers.
byte rowPins[ROWS] = {12, 13, 14};
// Arduino pins for the columns of the keypad.  RP Pico GPIO pin numbers.
byte colPins[COLS] = {0, 1, 2, 3, 4, 5, 6, 7, 8, 9, 10, 11};

// Pico GPIO pin number
#define NEOPIXEL_PIN 15 // RP Pico GPIO pin number
#define NUM_PIXELS 30 // Only 30 pixels in original neokey ordering.
Adafruit_NeoPixel strip = Adafruit_NeoPixel(NUM_PIXELS, NEOPIXEL_PIN, NEO_GRB + NEO_KHZ800);
#define GREENPIXEL 0x00006400
#define BLUEPIXEL 0x000000FF
#define REDPIXEL 0x00640000
#define WHITEPIXEL 0x00646464
#define KANAMODEKEY 5
#define KANAITERATE 11
#define KANAREPEAT 10

/*
 * An approach to associating key values to neopixels is to use the index formed 
 * for each group to map to a specific neopixel.  Note that indexes that do not
 * map to a specific neopixel is set to -1.
 */
const int8_t consoColorKeys[] = {-1, 18, 29, 19, 28, 20, 27, 21, 26, 22};
const int8_t shiftColorKeys[] = {-1, 25, 23, -1, 24};
const int8_t vowelColorKeys[] = {12, 13, 14, 15, 16, 17};
const int8_t speclColorKeys[] = {11, 10, 9, 8, 7, 6, -1, -1, 0, 1, 2, 3, 4, -1};

// Note that press key indexes corresponding to color
// keys with value of -1 will never be set to true.
bool consoPressKeys[] = {false, false, false, false, false, false, false, false, false, false};
bool shiftPressKeys[] = {false, false, false, false, false};
bool vowelPressKeys[] = {false, false, false, false, false, false};
bool speclPressKeys[] = {false, false, false, false, false, false, false, false, false, false, false, false, false, false};

// Uncomment lines above to debug neopixels once keyboard is debugged.

Keypad kpd = Keypad( makeKeymap(keys), rowPins, colPins, ROWS, COLS );

// Count of number of keys currently pressed for each key group.
byte consoCount;
byte shiftCount;
byte vowelCount;
byte speclCount;
byte indexRow, indexCol, shiftType;
bool kana, emit, speclKey; // Hirigana = false, Katakana = true.
char unicodeChars[4];

uint32_t getKanaUnicode(bool kana, bool special, uint8_t shift, uint8_t row, uint8_t col);

#define NEOPIXEL 1
/**
 * Function: kbd_setup - Initialze keyboard functionality, e.g., keyboard
 *   driver, keypad debounce, Neopixel driver.
 * Input: None.
 * Output: None:
 */
void kbd_setup (void) {
  strip.begin();
  strip.setBrightness(40);
  strip.show(); // Initialize all pixels to 'off'
  consoCount = 0;
  shiftCount = 0;
  vowelCount = 0;
  speclCount = 0;
  kana = false;
  speclKey = false;
  indexRow = 0;
  indexCol = 0;
  shiftType = 0;
  
  strip.setPixelColor(KANAMODEKEY, GREENPIXEL);
  for (int i = 0; i < sizeof(consoColorKeys); i++) {
    if (consoColorKeys[i] != -1)
      strip.setPixelColor(consoColorKeys[i], GREENPIXEL);
  }
  for (int i = 0; i < sizeof(vowelColorKeys); i++) {
    if (vowelColorKeys[i] != -1)
      strip.setPixelColor(vowelColorKeys[i], GREENPIXEL);
  }
  for (int i = 0; i < 2; i++) {
      strip.setPixelColor(speclColorKeys[i], GREENPIXEL);
  }
  for (int i = 2; i < sizeof(speclColorKeys); i++) {
    if (speclColorKeys[i] != -1)
      strip.setPixelColor(speclColorKeys[i], WHITEPIXEL);
  }
  for (int i = 0; i < sizeof(shiftColorKeys); i++) {
    if (shiftColorKeys[i] != -1)
      strip.setPixelColor(shiftColorKeys[i], WHITEPIXEL);
  }

  strip.show();
  kpd.setDebounceTime(40); // 40 ms debounce works better that default 20 ms.
}
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

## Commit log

2024-08-24 Initial commit of pictorial schematics
2024-08-24 Initial commit of neokey cut apart.
2024-08-24 Initial commit of left and right keyboard wiring.
2024-08-26 Initial commit of power wye.
2024-08-26 Initial commit of display wiring.
2024-08-27 Initial commit of KanaChord Plus STL files.
    [KanaChordPlus-bolt.stl, KanaChordPlus-casebridge.stl, KanaChordPlus-display-front.stl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]
2024-08-29 Initial commit of cable connects.
2024-08-29 Initial commit of display assembly.
    Commit early, commit often!
2024-08-29 Initial commit of keyboard assembly.
2024-08-29 Initial commit of base and feet attachment images.
2024-09-07 Initial commit of files used to generate dictionary header files.
    [Core10k.csv, Core5kFrequencyMod3.csv, Core6kMod.csv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]
2024-09-08 Initial commit of Arduino compiler images.
2024-09-08 Initial commit of top-level flowchart.
2024-09-10 Update of top-level flowchart.
2024-09-10 Initial commit of lower-level functions flowcharts.
2024-09-15 Updated display setup flowchart.
2024-09-16 Commit of update flowchart.

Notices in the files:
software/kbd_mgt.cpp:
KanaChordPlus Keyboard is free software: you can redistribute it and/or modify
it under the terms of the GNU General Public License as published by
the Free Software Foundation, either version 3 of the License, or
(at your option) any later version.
